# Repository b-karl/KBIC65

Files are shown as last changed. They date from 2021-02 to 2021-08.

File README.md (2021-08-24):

# KBIC65
A 65% [mechanical keyboard](https://keyboard.university/100-courses/intro-to-mechanical-keyboards) with a [ProMicro](https://deskthority.net/wiki/Arduino_Pro_Micro) controller footprint. Repository contains [KiCad](https://www.kicad.org/) PCB design files and 2D drawings in SVG of PCB, bottom plate, switch plate and acrylic window.

Bottom of keyboard has two alternatives. A design with glass rims inspired by my grandfather's glasses and a dithered image of the sun from the [NASA Solar Dynamics Observatory](https://svs.gsfc.nasa.gov/13641). Included below is also a [guide on creating dithered PCB art](#making-dithered-pcb-art-for-kicad).

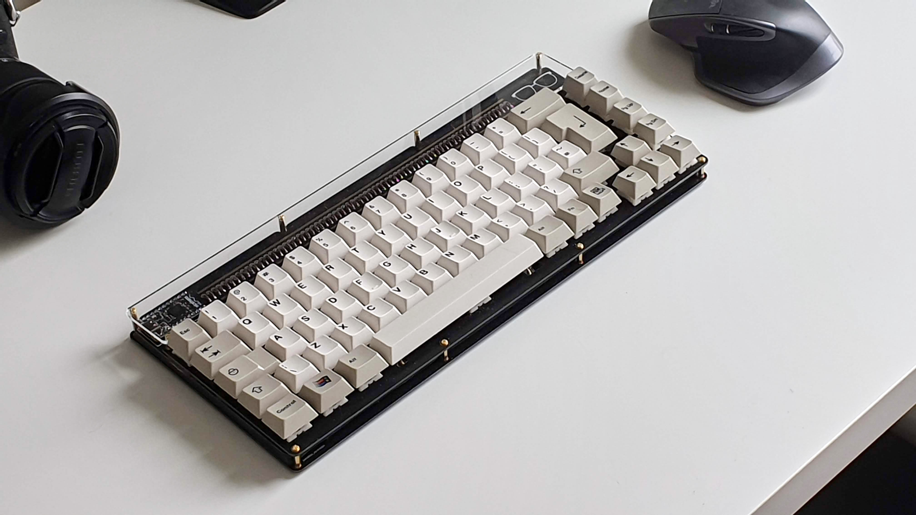
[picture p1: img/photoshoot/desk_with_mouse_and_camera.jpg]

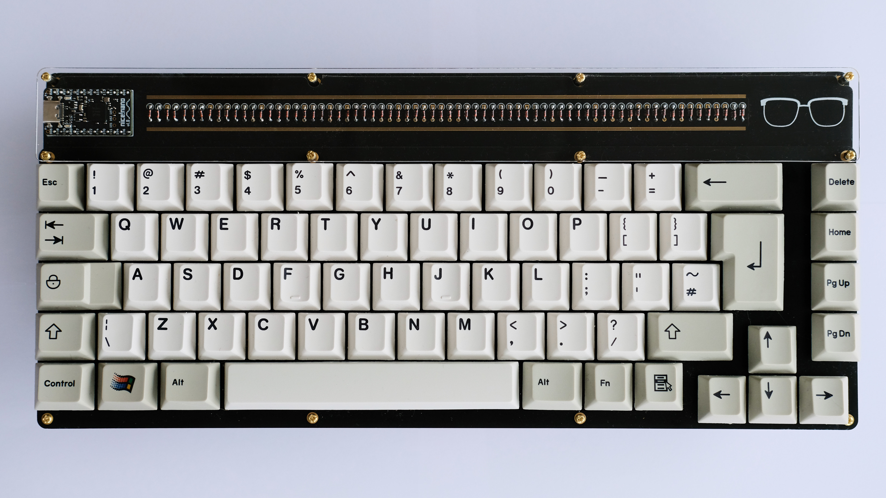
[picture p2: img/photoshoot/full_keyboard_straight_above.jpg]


[More photos](img/photoshoot/readme.md)

# Main features/focus
- Intended to be portable and wireless, but with a [through-hole technology (THT)](https://en.wikipedia.org/wiki/Through-hole_technology) style
- 65%/70 key layout with spaced arrow keys and right-side navigation row in the style of [Satistifaction75](https://cannonkeys.com/collections/group-buy/products/gb-satisfaction-75-keyboard-round-2) and many others
- ProMicro footprint to allow upgrade of the microcontroller, intended to be used with the [nice!nano](https://nicekeyboards.com/nice-nano/) and [ZMK](https://zmkfirmware.dev/) firmware for my personal build
- Designed to be mountable in both an open PCB stack or in a plate-mounted case (not yet designed)
- 8x9 wiring [duplex matrix](https://wiki.ai03.com/books/pcb-design/page/matrices-and-duplex-matrix) requiring only 17 pins on a ProMicro compatible controller

# Some design choices

- Reduced copper coverage on top of PCB and bottom plate, and no copper switch plate to improve Bluetooth signal
- Plate mounted with screws, the PCB contains drilled holes large enough to fit M2 spacers. I.e. the PCB is only connected to the plate via the switches.
- Tried to avoid vias, but have one (that I probably could have skipped)
- Since the bottom is symmetrical, there are two alternative design two choose from

# How to create your own
[See the v1.0 release](https://github.com/b-karl/KBIC65/releases/tag/v1.0.0) to find the files and list of parts to create your own. 
- Gerber zip-files are used to order the PCB, bottom plate and top plate from a PCB manufacturer, I used [JLCPCB](https://jlcpcb.com/). 
- The acrylic window can be ordered from any laser cutting firm working with acrylic, I live in Sweden and used [TechStation](https://techstation.se/en/). 
- For keycaps, switches and ProMicro-compatible controller (possibly also diodes) use a keyboard company in your region, I got my keycaps from [KBDfans](https://kbdfans.com/), diodes from a local electronics supplier and the rest from [Splitkb](https://splitkb.com/).
- Screws and stand-offs can be sourced from various places but are probably easiest to find on AliExpress.

I do not have dedicated assembly instructions, but if you are comfortable soldering you can probably make do using [my build log](build_log.md).
# Firmware
I decided to use [ZMK](https://zmkfirmware.dev/) for my build of this keyboard. Compared to the most common open source mechanical keyboard firmware [QMK](https://docs.qmk.fm/#/), ZMK is tailored for wireless keyboards. The two main reasons you should care to use ZMK instead of a bluetooth QMK fork are (1) much better power efficiency, i.e. longer battery life, and (2) the most commonly used Bluetooth chip uses drivers that are not compatible with the QMK copyleft license.

You can find my ZMK shield for the KBIC65 in [my ZMK config repository](https://github.com/b-karl/zmk-config).

If you want to use a non-wireless controller (like a ProMicro, Elite-C etc.), I have [created a QMK fork](https://github.com/b-karl/qmk_firmware/tree/add-kbic65-keyboard/keyboards/karlb/kbic65) that has been tested on the KBIC65 using an Elite-C rev 4.

# Layout options



# Components

## PCB Front

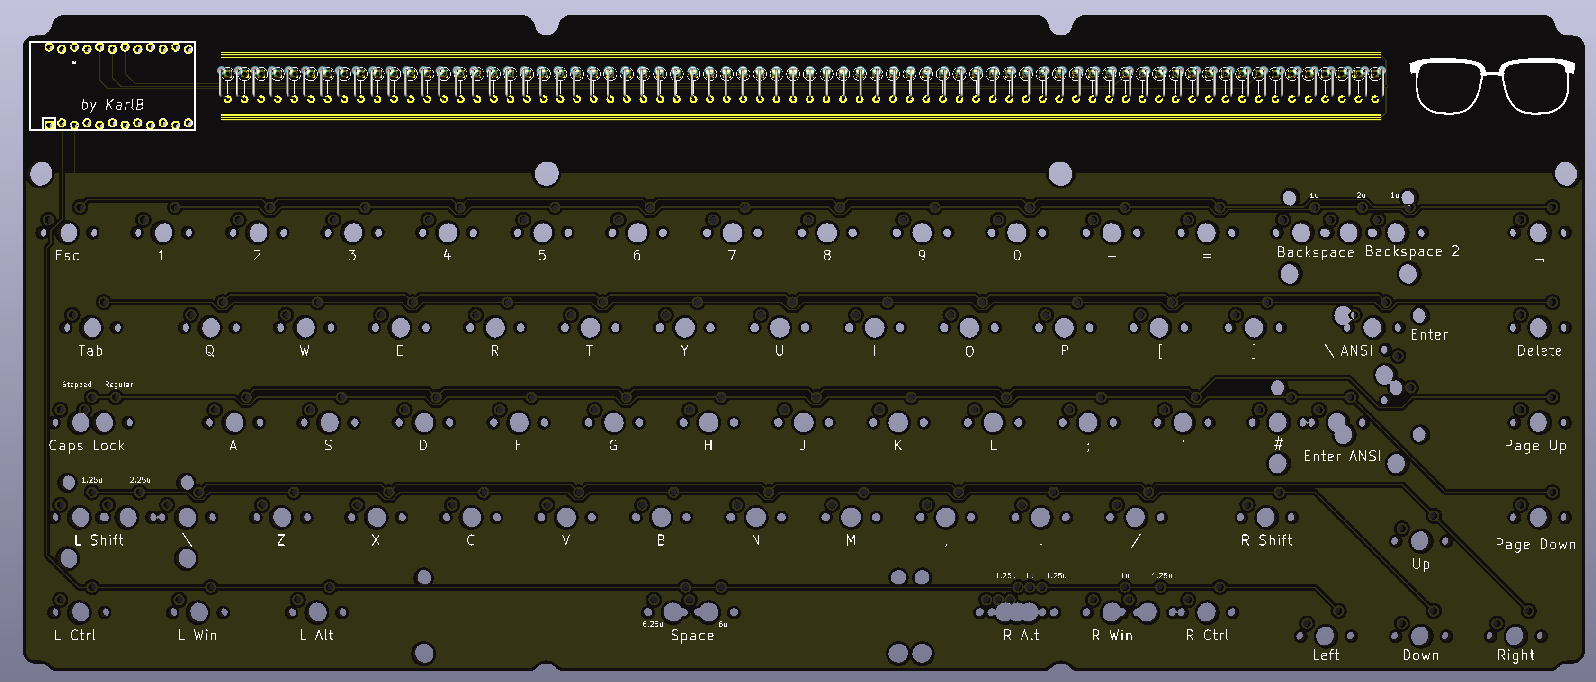
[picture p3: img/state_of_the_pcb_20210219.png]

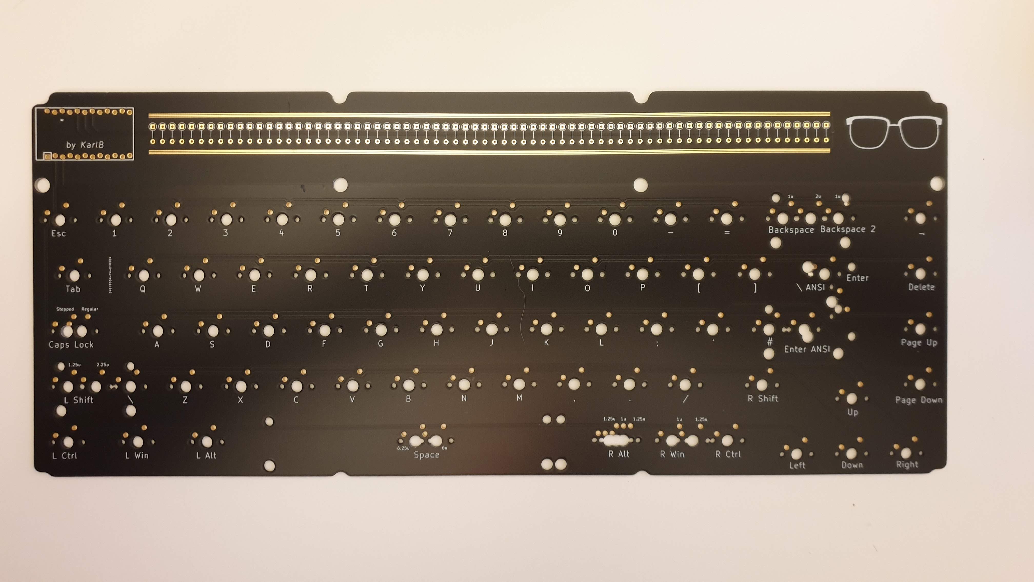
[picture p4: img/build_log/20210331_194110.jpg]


## Plate

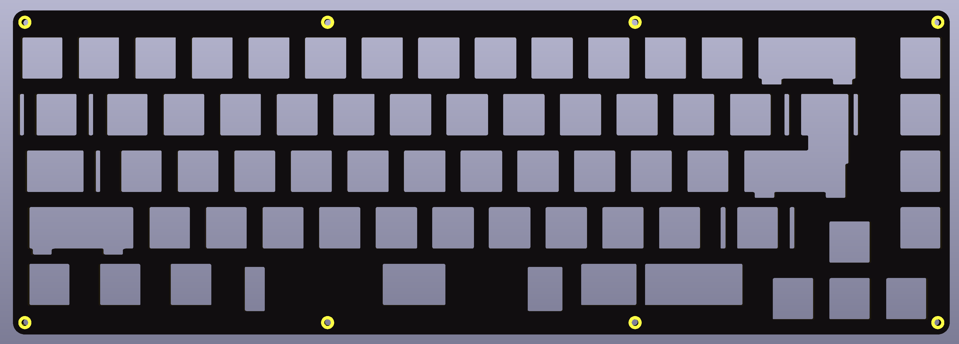
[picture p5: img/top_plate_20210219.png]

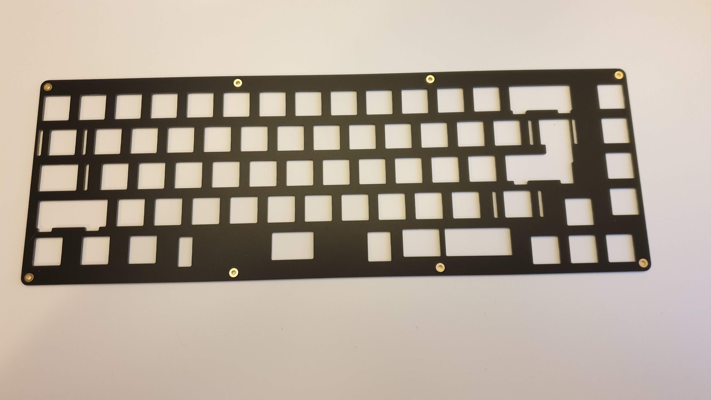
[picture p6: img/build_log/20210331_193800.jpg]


## Bottom Option 1 (PCB Front)

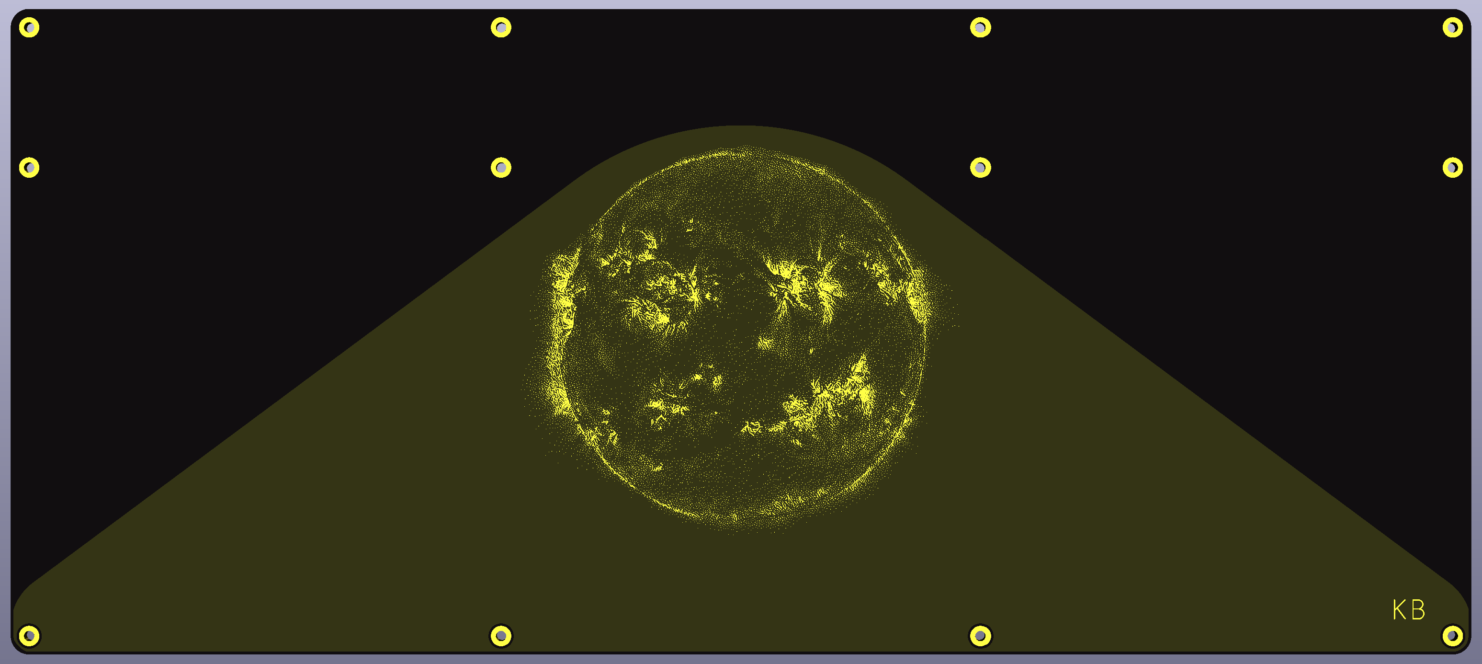
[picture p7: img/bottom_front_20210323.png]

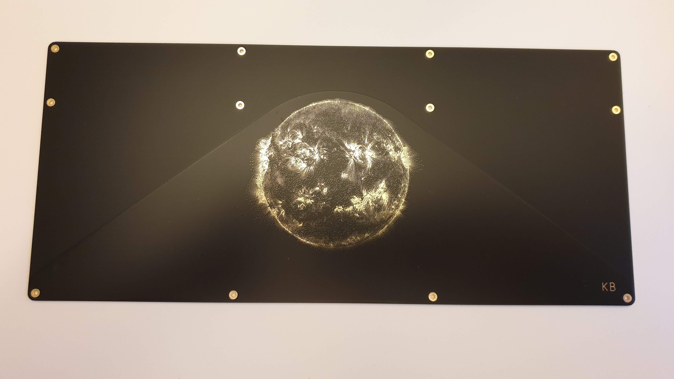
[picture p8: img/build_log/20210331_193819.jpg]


## Bottom Option 2 (PCB Back)

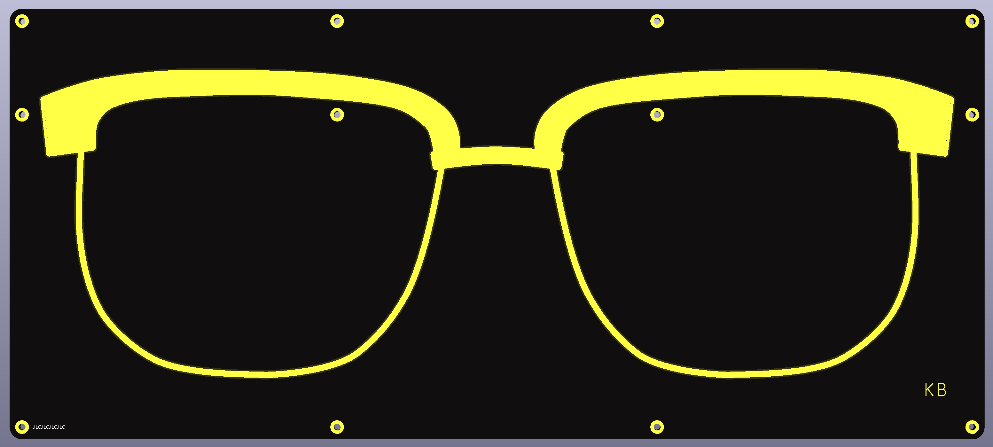
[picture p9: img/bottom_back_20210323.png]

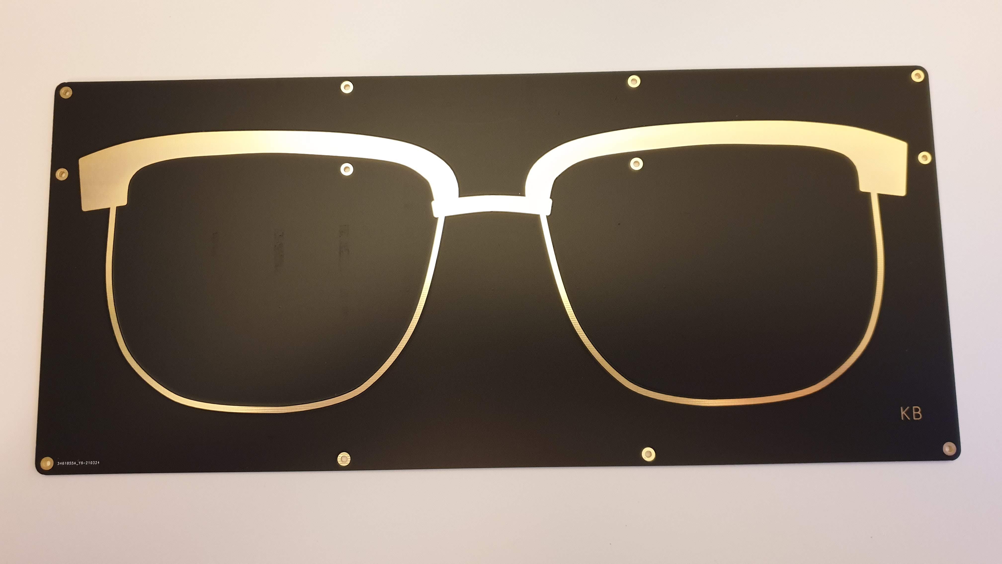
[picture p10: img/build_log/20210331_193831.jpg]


# Making dithered PCB art for KiCad
When I decided to make an alternative design for the bottom I eventually settled on trying my hand at a dithered image. This was a little trickier than I expected to get looking like I wanted (and still not sure how the end result will appear).

But generally here is the workflow I used in the end, and would recommend
- Settle on an image to use, crop it to only the part you want to place on the PCB. I settled on a NASA SDO image.


- JLCPCB and probably other PCB manufacturers can print at a resolution of about 0.15 mm which is equivalent to about 169 DPI. This means you should try to use 169 DPI or less, I used 169 DPI. Resize your image so that the resolution of the image at your selected DPI gives you the size you want on the board. I wanted my sun to be approximately 90 mm high so I resized to 600px high, which results in an image 90.2 mm high at 169 DPI. 
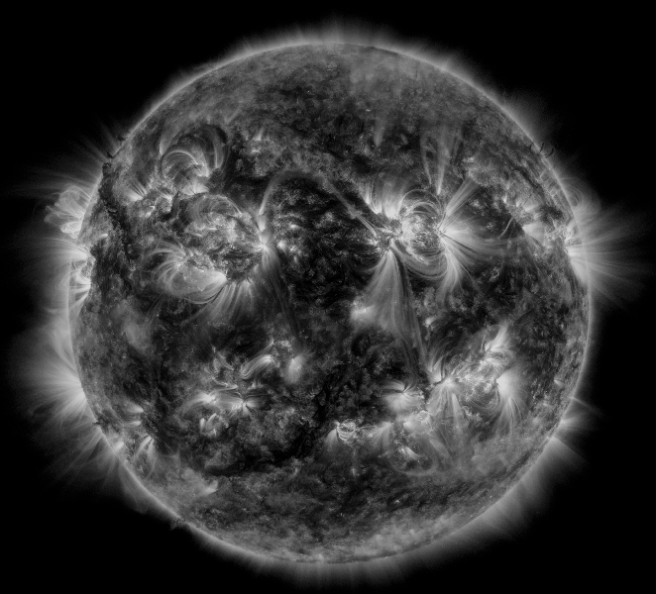
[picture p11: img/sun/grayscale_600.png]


- Use a dithering tool to dither your image and create a dithered copy. I strongly recommend [Ditherlicious](https://29a.ch/ditherlicious/) but you can look around for other tools you have handy.
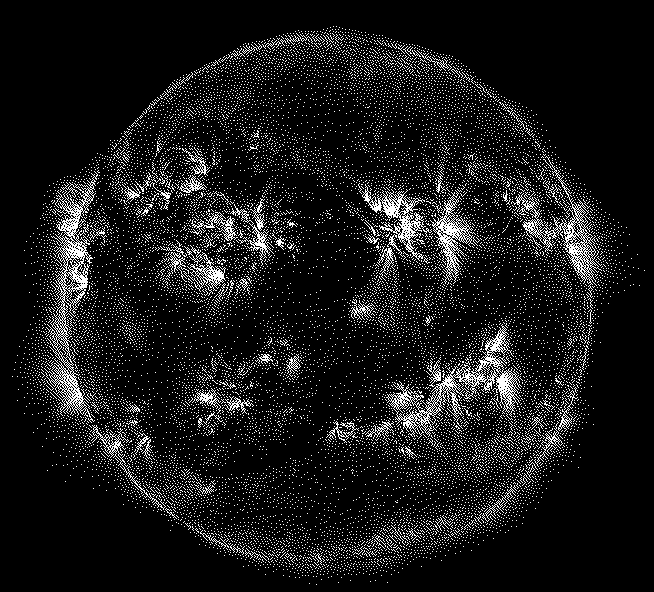
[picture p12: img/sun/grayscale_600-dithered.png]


- Open your KiCad project and then open Convert Image, a.k.a. the bitmap2component tool.
- Import your dithered image, select Negative if necessary, pick either Front Silk Screen or Front Solder Mask and enter your chosen DPI. Click export and put into a new folder that will become a new KiCad library for you.
- In Pcbnew or your KiCad project, open Preferences > Manage footprint libraries
- Add your new folder as a footprint library
- Import your new PCB art footprint onto your PCB
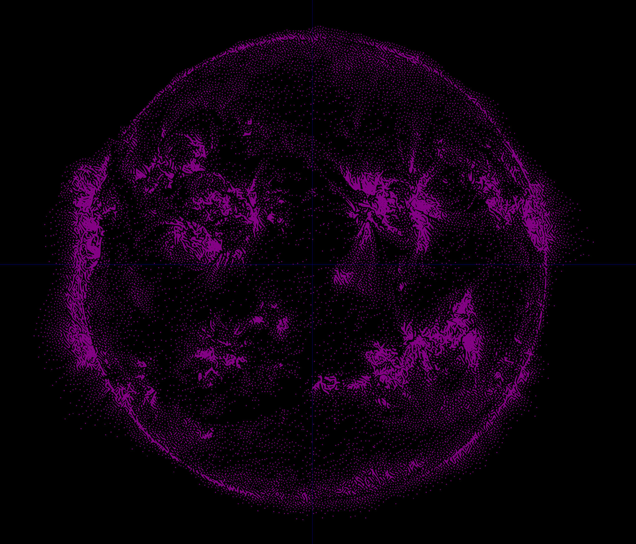
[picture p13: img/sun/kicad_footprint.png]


- Iterate, I played a lot with different dithering tools, changing the image histogram etc. The bitmap2component tool does not import dithered image exactly but blends pixels together, therefore I would recommend generating a few variants and comparing them in KiCad and possibly the 3D viewer. Please note that these images requires quite a bit of processing from KiCad. Updating the 3D view especially, which took about 1-2 min for me.

- Final result after ordering from JLCPCB with black solder mask and ENIG finish
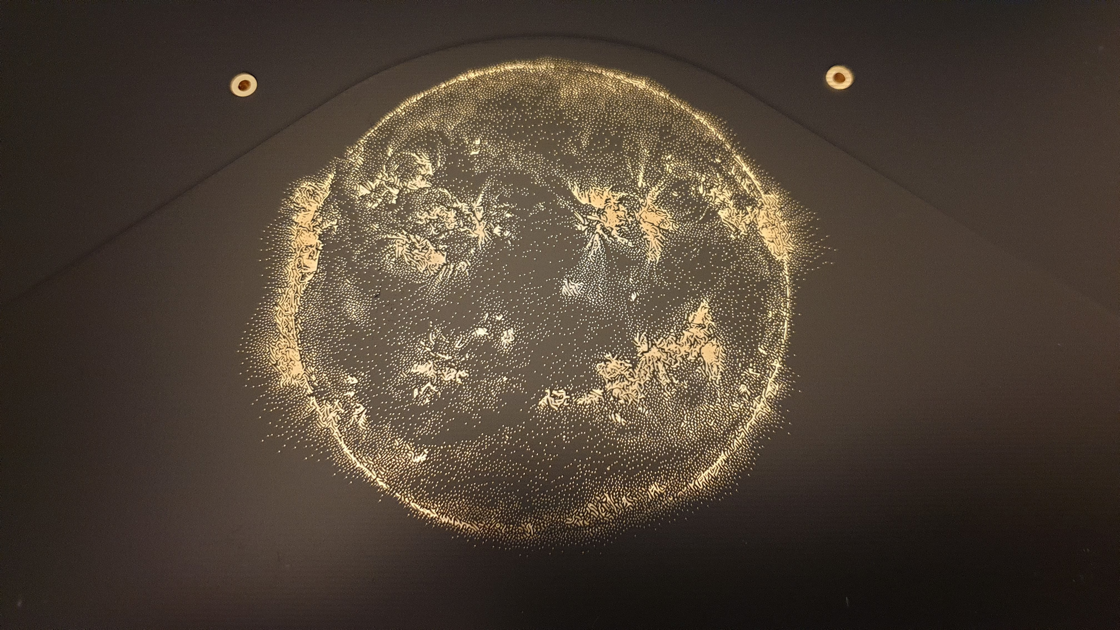
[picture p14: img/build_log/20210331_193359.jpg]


# Comparison to similar keyboards

## Discipline65
The [Discipline65](https://github.com/coseyfannitutti/discipline) is the original inspiration for this keyboard, along with the case making community that has been born around it. In the spirit of CFTKB the board design will also be open source.

Some of the main differences
- KBIC65 will use a dedicated ProMicro footprint instead of all the THT components in the Discipline65, a believe this makes the board more easy to upgrade at the cost of losing some of the THT aesthetic.
- The layers in the Discipline FR4 kit have the same outer dimension (excluding the top part of the plate), which is nice for a pure FR4-style keyboard but creates some limitations if one wants to create a case for it. The KBIC65 will have a minimal PCB given the layout (on the left, bottom and right sides) and a plate with overhang allowing for various types of plate-mounted case designs.
- The PCB will have holes large enough to fit M2 spacers between THT row and the layout. This allows the FR4 kit-style assembly to have the PCB completely free-floating and only the switch plate connecting directly to the bottom plate.

## Nibble65
The [Nibble65](https://nullbits.co/nibble/) is another board inspired by the Discipline65. It has an additional column of keys on the left, allowing also for rotary encoders and the top of this column houses a ProMicro footprint. 

Some differences
- The Nibble65 has similar limitations to the Discipline65 in terms of case design compatibility
- The Nibble65 uses multiplexers (I believe) to keep the PCB wiring simple and to add a bit to the THT aesthetic. The KBIC65 uses an efficient wiring matrix allowing for a full 65%/70 key layout without additional components.
- The Nibble65 has an extra column to the left, housing a ProMicro-footprint, some extra keys as well as a multi-purpose section for either rotary encodes, giant LED or an OLED screen.

# Possible future work
- Non-metal case
- Solar cell trickle charging panel instead of window
- Remove unintended silk screen from front PCB glasses
- Add holes for mounting a battery connector
- Move JLCPCB production number location (or get it removed in production)
- Change battery to something slightly thinner, sub-5 mm, but could be wider and longer than the current battery

# FAQ

### What does KBIC mean?
The original name KBIC65 is inspired by soldering and tinkering in my grandfather's workshop as a child and have named it with our combined initials KB and IC. But having spent quite a bit of time on making PCB art for the bottom of the keyboard based on an image from the [NASA Solar Dynamics Observatory](https://svs.gsfc.nasa.gov/13641) I am considering renaming it if I make anything more of it (or make a group buy at some point). I am open to name suggestions if you have one!

### Why don't you just buy keyboard X? It is cheaper and simpler than designing this.
I am doing this as a side project for fun, and the learning experience, and definitely not for profit.

If you want a 65% keyboard with the THT aesthetic get a [Discipline65](https://github.com/coseyfannitutti/discipline). If you want a 65% for your nice!nano, get the [Nibble65](https://nullbits.co/nibble/). If you just want something wireless but don't want to build it yourself, get a [Keychron](https://www.keychron.com/).

### I really want to make one myself, can you please fix the remaining issues?
Maybe, if you have some experience or willingness to learn, fork this repo and try to fix it yourself (and maybe do a PR on the end result). If you don't have the experience or know-how, send me a message so I know someone actually wants it and I will consider fixing it when I have time.

### This is just a rip-off of keyboard X. What gives?
I am trying to make my own thing but the design is of course heavily inspired by other keyboards, especially THT kits. Some honorable mentions

- [Nicell Dissatisfaction65](https://github.com/Nicell/Dissatisfaction-65)
A very similar keyboard to what I am designing, by the creator of the nice!nano. This uses a lot of the "early" techniques for what I feel a wireless open-source firmware was in 2019-beginning of 2020 such as Adafruit Feather BLE with QMK, something that is much better done today with the nice!nano (and similar controllers) and the ZMK firmware. Nicell is the creator of the nice!nano and also very active in the ZMK project.

- [CannonKeys Satisfaction75](https://ilumkb.com/blogs/news/satisfaction-75-r2)
My original inspiration for the layout

- [CFTKB Discipline65](https://github.com/coseyfannitutti/discipline)
Original inspiration for the THT design and the idea to make an FR4 kit first and a case after. The open-source Kicad files have also been a good sanity check, plus it has beautiful wiring!

- [Nullbits Nibble65](https://nullbits.co/nibble/)
A great take on the THT and would be my choice to buy if I didn't want to make something of my own but still make a nice!nano keyboard.

- [Lysol LCK75](https://p3dstore.com/products/lck75): No diode row but THT components otherwise and that arrow keys and navigation column stagger.

- [MujiManic Disarray65](https://sneakbox.com/products/disarray): Not exactly THT, but sooo much fun, beautiful wiring and one of the best case ideas ever. Case also comes in a version for the Discipline.

- [RMI-KB Herringbone75](https://rmi-kb.com/herringbone/): A fun variant on the Mysterium 75.

- [u/emdarcher Lattice 60%](https://keyhive.xyz/shop/lattice): Definitely contender for most innovative diode placement among THT keyboards

- [theksmith Discipline65](https://theksmith.com/hardware/designing-building-custom-mechanical-keyboard-2020/): Honorable mention on Discipline65 case design

- [4Bar60 by u/struct_Nodes](https://www.reddit.com/r/MechanicalKeyboards/comments/kyjpx3/my_girlfriend_surprised_me_with_a_breakup_before/)
I found this keyboard in the middle of my PCB design but it is very similar to my intended design, except being a 60% of course.

- [WorldspawnsKeebs Houndstooth](https://www.etsy.com/uk/listing/717316405/houndstooth-kit-does-not-include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)
A split ortholinear 4x6 with a nice take on a clear case

- [Seoulcialite Argyle60](https://geekhack.org/index.php?topic=106255.0)
Great case for a THT kit and very interesting with side windows instead of placed above the key layout. Inspiration for moving the ProMicro footprint and diode row up 1/4 units to allow top case to have a divider between main layout and THT window.

- [EBastler Isometria75](https://github.com/ebastler/isometria-75)
Makes me want to try to change the key spacing on my keyboard, but I am unfortunately not brave enough.

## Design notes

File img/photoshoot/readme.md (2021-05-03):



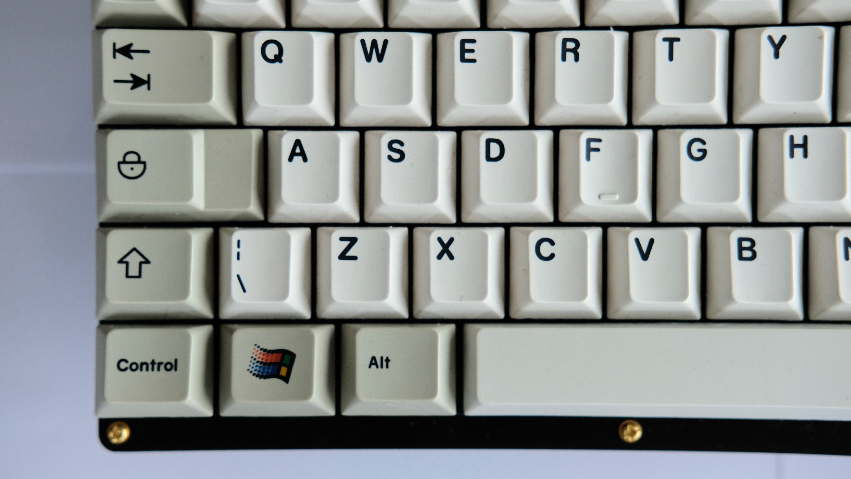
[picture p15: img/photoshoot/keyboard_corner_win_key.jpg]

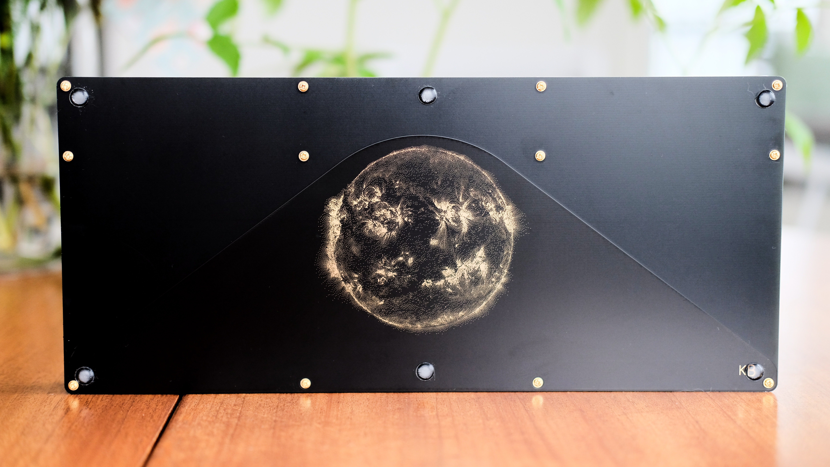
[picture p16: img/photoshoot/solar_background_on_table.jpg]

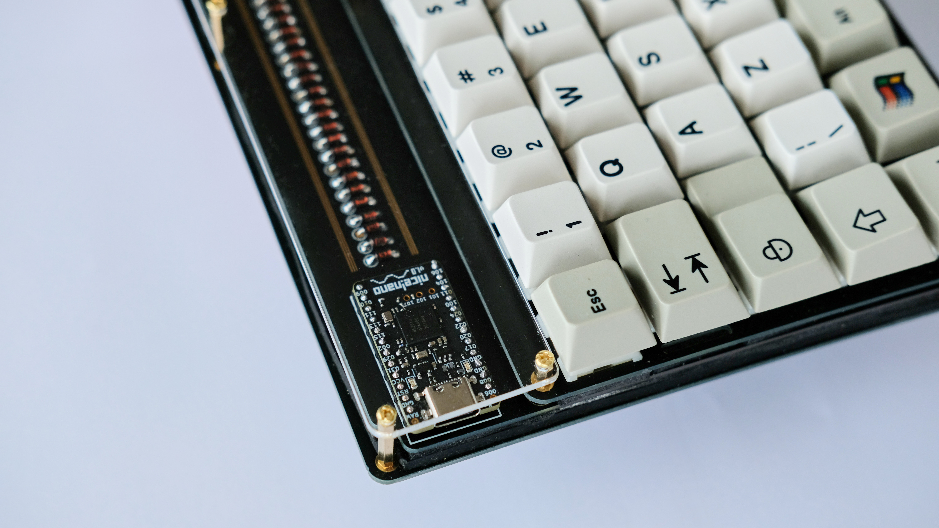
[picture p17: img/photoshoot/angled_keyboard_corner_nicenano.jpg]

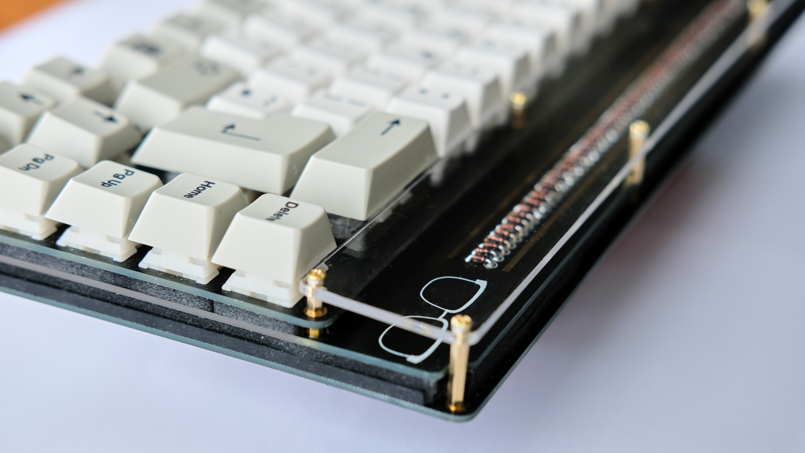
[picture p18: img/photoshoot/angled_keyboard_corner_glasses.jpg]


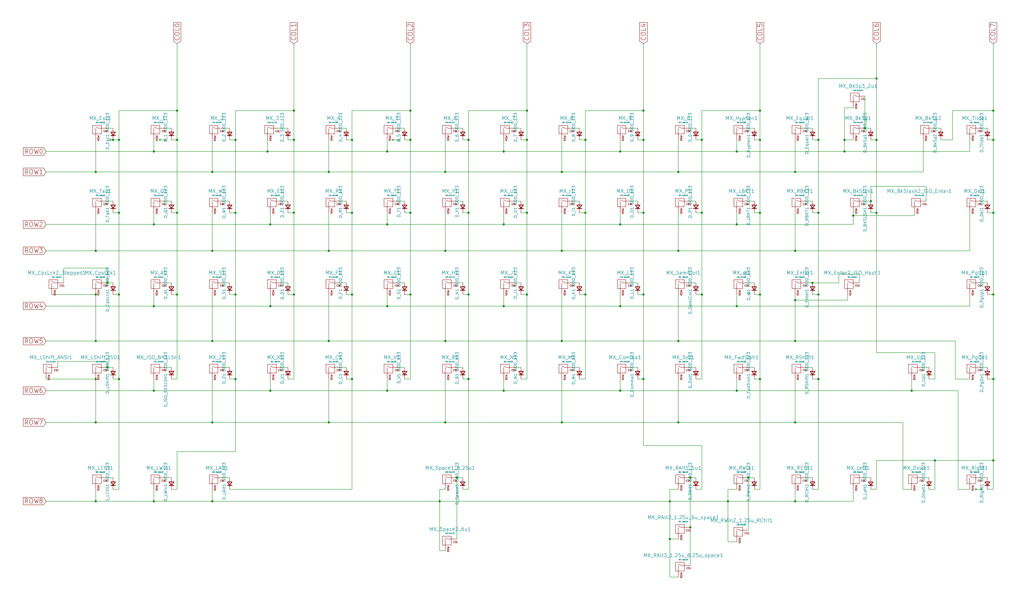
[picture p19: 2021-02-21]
img/matrix_schematic.png

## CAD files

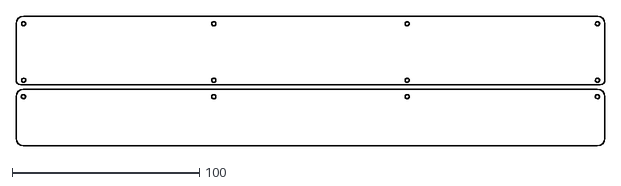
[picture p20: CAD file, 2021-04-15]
drawings/Window_Combined.dxf
314.4 x 69.1

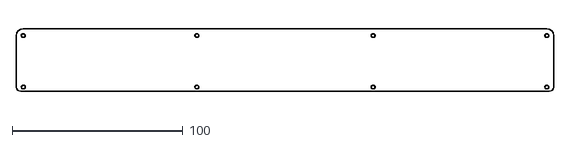
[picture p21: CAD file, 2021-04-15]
drawings/Window_Large.dxf
314.3 x 36.5

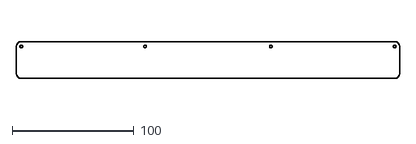
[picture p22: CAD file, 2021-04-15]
drawings/Window_Small.dxf
314.3 x 30.2

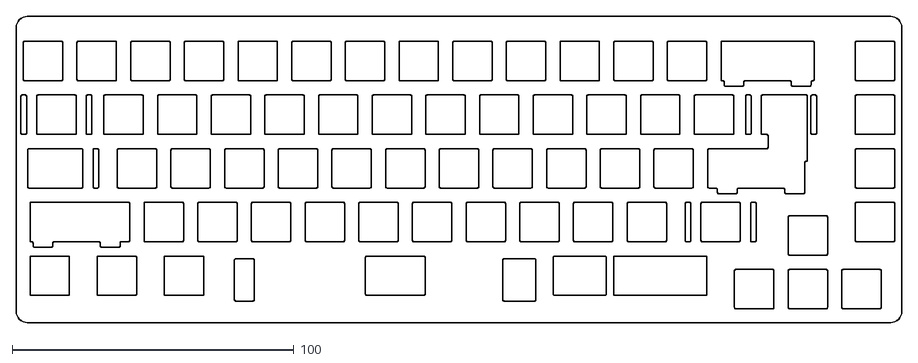
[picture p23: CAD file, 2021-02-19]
drawings/Plate_Outline.dxf
314.3 x 108.7

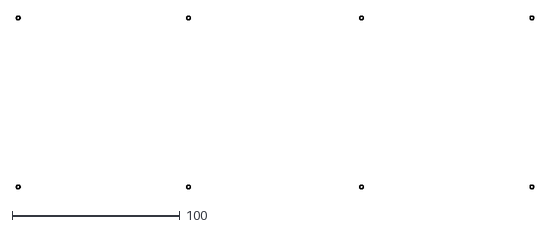
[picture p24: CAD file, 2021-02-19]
drawings/Plate_Holes.dxf
308.7 x 103.1

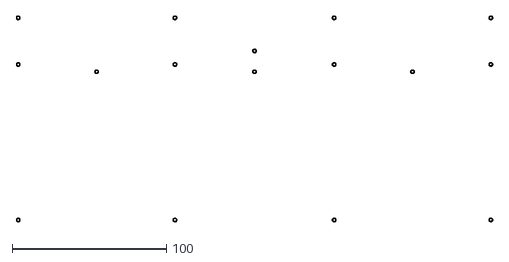
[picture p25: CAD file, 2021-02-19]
drawings/Bottom_Holes.dxf
308.7 x 133.3

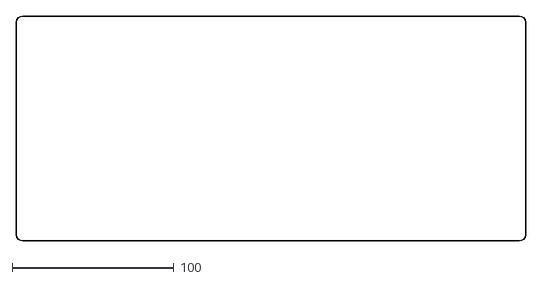
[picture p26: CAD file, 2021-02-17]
drawings/Bottom_Outline.dxf
314.3 x 138.9

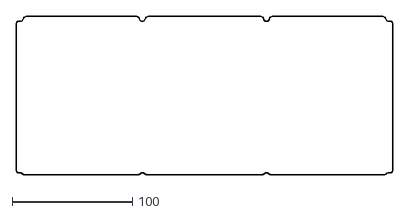
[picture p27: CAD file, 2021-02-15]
drawings/PCB_Outline.dxf
313.3 x 131.6

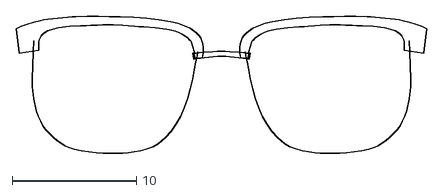
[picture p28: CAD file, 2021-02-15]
drawings/PCB_Silkscreen.dxf
33.0 x 11.1

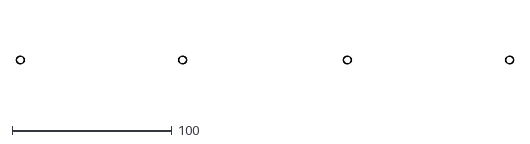
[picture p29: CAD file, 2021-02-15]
drawings/PCB_Holes.dxf
311.4 x 5.22

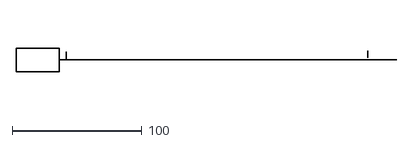
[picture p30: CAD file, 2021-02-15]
drawings/PCB_TopReference.dxf
293.4 x 17.8

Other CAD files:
drawings/Bottom_Silkscreen.dxf

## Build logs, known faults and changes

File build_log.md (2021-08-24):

# KBIC65 Build Log
Overview of build steps
- Prepare nice!nano
    - Set up ZMK and generate uf2 file
    - Load firmware with keymap
- Prepare foam/rubber layers (optional)
    - Attach plate foam
    - Cut out neoprene sheet
- Prepare bottom plate
    - Attach rubber feet
    - Attach spacers to align components
- Prepare PCB
    - Solder on diodes
    - Socket nice!nano
    - Test PCB
- Prepare and attach stabilizers
    - Stabilizer foam / band-aid mod
    - Clipping (not necessary)
    - shrink tube mod (reverted after testing)
    - Lube
    - Attach stabilizers
- Assemble plate-PCB package
    - Attach and solder on switches
    - Test assembled module
- Assemble keyboard without battery
- Test keyboard
- Add battery
- Test again (now with Bluetooth!)
- Put on keycaps
- Enjoy!
- Remember you were supposed to put on am acrylic window, order it and wait

# Recommended components
- 1 KBIC65 PCB
- 1 KBIC65 bottom plate
- 1 KBIC65 switch plate
- 1 KBIC65 2 mm acrylic window
- 1 [nice!nano](https://nicekeyboards.com/nice-nano/)
- 70 [1N4148 diodes](https://en.wikipedia.org/wiki/1N4148_signal_diode)
- 6 domed rubber feet
- 24 M2 x 4 mm brass bolts
- 8 M2 x 10 mm female-female brass standoffs
- 4 M2 x 15 mm female-female brass standoffs
- 4 M2 x 3 mm male-female brass standoffs
- 70 MX-style switches

Bolts and standoffs are most easily acquired via AliExpress, at least in Sweden where I am.

And if you want to put in foam
- 3-5 mm bottom-PCB foam or rubber (there is 3 mm clearance, 5 mm requires cutting out holes around pins sticking down). I used [3 mm neoprene](https://www.swedol.se/neoprengummipg-1001022.html) plus some leftover plate foam on the sides to seal it.
- [Plate-PCB foam](https://kbdfans.com/collections/keyboard-foam/products/kbdfans-module-foam)

# Prepare nice!nano
I had been looking at how to create a custom wireless keyboard for a while. My initial research suggested using an Adafruit Feather BLE with QMK, such as the [Dissatisfaction65 by Nicell](https://github.com/Nicell/Dissatisfaction-65), but luckily just a few months earlier Nicell himself had created the nice!nano controller, which is a ProMicro footprint Arduino close with Bluetooth. Even better, I found there was a relatively new keyboard firmware project called [ZMK](https://zmkfirmware.dev/), that addressed a bunch of the issues that QMK has with wireless. The two primary issues resolved by ZMK is (1) more battery-efficient scanning algorithms to improve battery life and (2) a license that is compatible with the Bluetooth libraries since QMK is not legally compatible with the libraries required to run Bluetooth chips.

In addition, however, ZMK has learned a lot from how QMK is used and also improved other aspects of the project, such as minimal user repositories that hosts your personal keymap and keyboard configurations and that then builds the ZMK firmware using GitHub Actions. A really neat setup in my opinion. Of course, they still don't have VIA or something like the QMK web tool, but in my case I was building my own PCB and matrix and therefore would need to dig into some code either way.

ZMK has pretty good documentation, but it also helped looking at other ZMK user repositories. My recommended reading guide order someone new to ZMK and that would like to replicate my work would be
1. [Read the introduction](https://zmkfirmware.dev/docs/)
2. [Read the FAQ and understand the difference between board and shield](https://zmkfirmware.dev/docs/faq)
3. [Set up a ZMK user repo](https://zmkfirmware.dev/docs/user-setup)
4. [Create a new shield](https://zmkfirmware.dev/docs/development/new-shield/)

I then used the [Nibble ZMK shield](https://github.com/zmkfirmware/zmk/tree/main/app/boards/shields/nibble) as a reference, there are probably better options though since the Nibble has an extra column to the left, a multiplexer for the matrix and support for rotary encoders, all of which I didn't need for my build.

I then created a first keymap, pushed to my [personal config repo](https://github.com/b-karl/zmk-config) and with some [ZMK GitHub Actions magic](https://github.com/b-karl/zmk-config/actions) I could download a uf2 file to flash my nice!nano with.

The nice!nano was super-easy to flash with a new firmware since it uses a bootloader that makes it show up as a mass-storage device. Then it is simple copy-paste or drag-and-drop of the new .uf2 file to the device and once the transfer is complete it automatically flashes itself and voilà, a new keyboard is detected.

# Prepare foam and rubber
## Plate foam
This is my second keyboard build, my first was a KBD75v2 kit from KBDfans. For that build I got [plate foam](https://kbdfans.com/collections/keyboard-foam/products/kbdfans-module-foam) and I had enough leftover to also cover this build. The modular plate foam is most easily placed using a tweezer to avoid deforming the pieces to much before the glue touches the plate. I also tried to keep the surrounding edges clean since they will be visible from the sides. 

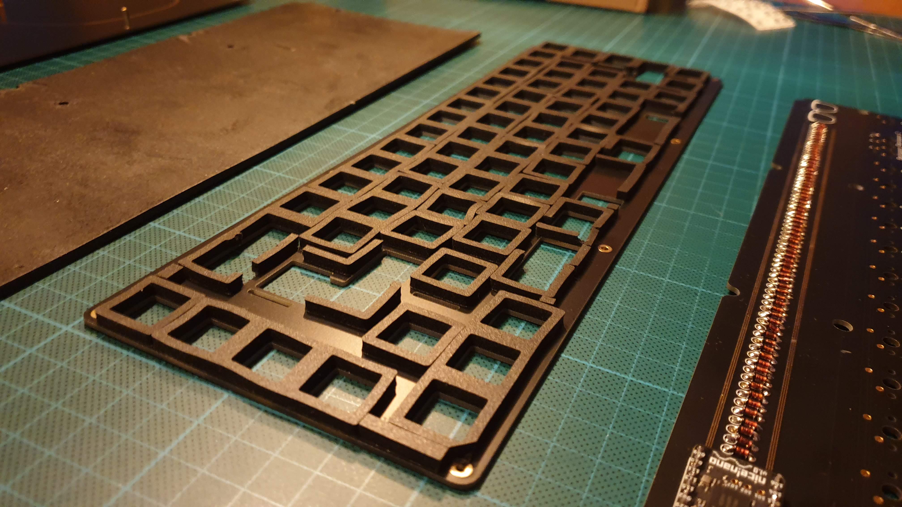
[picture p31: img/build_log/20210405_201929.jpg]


Unfortunately, I was a little too eager with covering everything. It turned out when I was assembling the plate and PCB  that some of the foam I had put in around the stabilizers was pressing on them, so I had to disassemble my work so far and clean up all the foam above and below the stabilizer mounts and along the stabilizer wire.

## Case foam/rubber
To add some weight and sound dampening without impeding the wireless signal too much, I decided to add a [3 mm thick neoprene rubber](https://www.swedol.se/neoprengummipg-1001022.html) cutout between the PCB and the bottom plate. I took one of my spare PCBs and used it to draw the outline on my neoprene sheet and then I used a carpet knife and a hole puncher to create the shape.

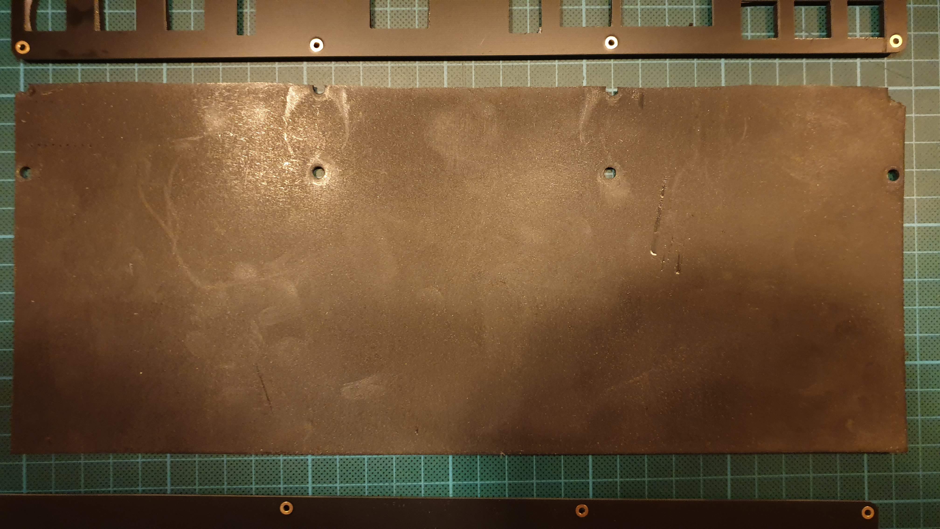
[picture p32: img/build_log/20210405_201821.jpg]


### Some notes on silencing a mechanical keyboard (or controlling sound profile)

Doing some research on how to dampen the sound of the keyboard (since I want to use it at my office in the future without pissing off my colleagues) the factors that I have understood to be most important, and think makes sense from my limited experience with two keyboards are the following

- Use a silent linear, silent tactile, linear or tactile switch (on order of most to least silent), a clicky switch is by definition not silent.
- Weight is one of the most important factors, the heavier the better so metal cases are better than plastic ones. This goes in conflict with a wireless build so I opted to aim to make the keyboard as heavy as possible without using metals that might shield the Bluetooth signal.
- Put the keyboard on a soft desk mat.
- Fill up hollow spaces in the keyboard with foam, rubber or some other material. Foam makes most sense usually since it probably has the least impact on the flexibility and motion of the plate and thus the give with each keystroke.
- Use a softer plate material, aluminum is usually considered OK among metal but brass and steel might cause ping sounds.
- Band-aid mod stabilizers and possibly shrink tube mod them.
- Lube stabilizers
- Lube switches

If you have done all of the above and want to try something else, you can try - Putting O-rings on the key cap stems. The idea with this is that it will dampen the sound when bottoming out, but it might also make the keys feel more mushy and reduces key travel somewhat. If and how well it works also depends on your key cap profile and materials. This mod is a very loaded subject on r/mk and I think it has very little impact compared to the points above.
- Fill larger keycaps, or if you're extreme all keycaps, with foam to remove and reverb inside the keycap. This mod is most commonly done for the space bar.

### Choice of case foam
Since I wanted my case foam to both be a good sound absorber and provide as much weight as possible the options I found most suitable were:
- Sorbothane: Expensive and hard to get in a good size if you have an open case design as my first iteration will be
- Butyl rubber or similar: Used for sound deadening in cars and the best alternative I found was something like [Dynamat Dynaliner](https://www.amazon.com/Dynamat-11101-Dynaliner-Self-Adhesive-Deadener/dp/B001KM9C4C). Issues with this was once again price but I also read that it can smell quite a bit and it takes a while before the smell goes away, which again is maybe not the best choice with an open case design. The benefit would, however, be that it is probably the heaviest of the options around.
- High-density EVA foam: Relatively cheap but dense foam commonly used for cosplay and role playing.
- Neoprene rubber: Also relatively cheap and available.

Comparing these I ruled out sorbothane and butyl rubber, leaving HD-EVA and neoprene. Out of these I then looked up the common densities of these materials and neoprene won by a small margin so I settled on neoprene.

# Prepare bottom plate
As they always say in keyboard build videos, start with putting rubber feet on your case to protect it from scratches. In addition, it will also be nice to occasionally use the bottom and neoprene sheet as a base when working with the PCB and plate.

For screws and spacers I wanted them to be in brass, or look like golden brass at least. This was a bit tricky to find in Sweden, but I eventually learned that Amazon is a pretty good source for random screws and I picked up [this kit](https://www.amazon.se/gp/product/B087N3Z4RY/ref=ppx_od_dt_b_asin_title_s00?ie=UTF8&psc=1), giving me some flexibility if I want to play with the mounting. I attached 10 mm spacers to the bottom and then put the neoprene on for the moment. The neoprene feels like a good soft surface to rest the PCB once diodes, controller and switches are soldered in.

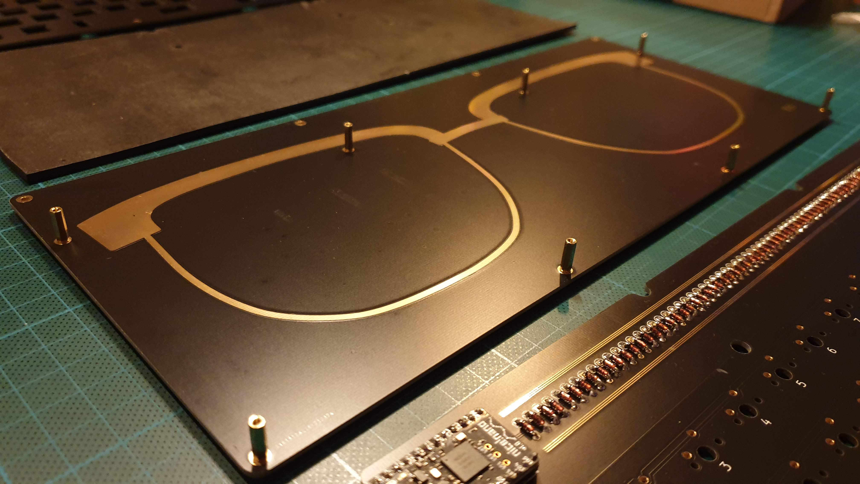
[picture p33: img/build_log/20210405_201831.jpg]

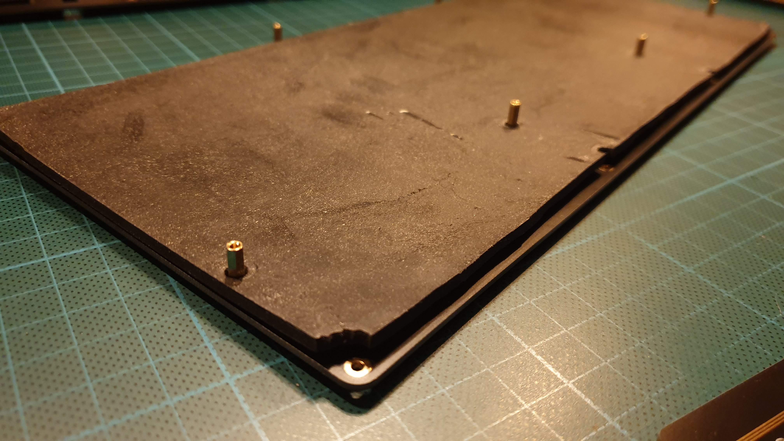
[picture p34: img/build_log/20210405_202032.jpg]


# Prepare PCB
There is no real test like getting something to run in real life. I ran checks in KiCad when developing my PCB and in addition, JLCPCB do probe testing to check the PCB. I could, of course, have messed up something more fundamental in my design that wouldn't be caught in any of these checks.

To get the PCB up and running required two general steps
- Attach the nice!nano (which I did by socketing it so I can remove it easily if I want).
- Solder in diodes for all switches.

This is essentially just a bunch of soldering and ended up like this for me:
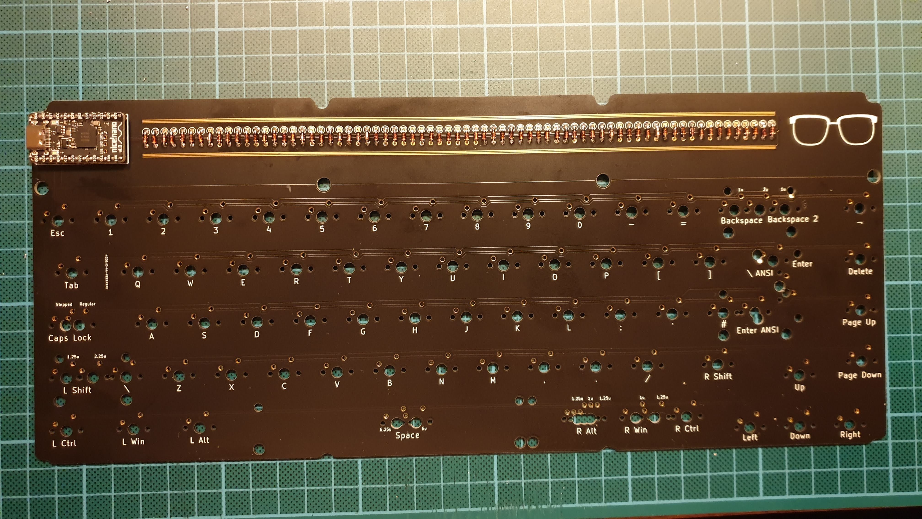
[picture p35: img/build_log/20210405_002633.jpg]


The tricky part, compared to soldering switches is that these joints are very visible and since the are on one long line, any inconsistencies show easily. I initially tried bending multiple diodes together when they where still in their package tape but I don't think it really worked better than just bending them one by one with my hands. This was also partially due to the footprint I selected for the diode essentially requiring the diode legs to be bent as close to the diode as possible.

One thing I would be more careful about if I did it again would be to try to be consistent with the amount of solder I used and the amount of time I spent heating up the solder and components. One of the aesthetic issues with the final result is that the solder came through from the back of the board and filled part of the front for several diodes, but not all, and this is probably the inconsistency that bothers me the most.

# Prepare and attach stabilizers

For stabilizers I got [Durock screw-in stabilizers v2](https://keygem.store/products/durock-screw-in-stablizer-v2-set?_pos=4&_sid=b89e1c812&_ss=r) with transparent plastic and brass/golden metal details. It was the stabs I could find that I think would go best with the rest of my build (black, white and gold).

## 6u stabilizer
For my first build with this PCB I wanted to use a 6u space bar to allow for a 1.25u Right Alt, which is heavily used when typing with a Swedish (or any ISO) layout. I knew they aren't that common, but luckily the ePBT 9009 kit I got for this keyboard has multiple 6u space bars to choose from. However, later when buying stabilizers I found out that 6u stabilizers are probably even more rare, especially if you want them looking a certain way. Doing a bit of research, the best course of action seemed to bend another stabilizer wire (or some other metal wire) to the correct length. Luckily, my Durock stabilizer set came with a 7u stabilizer wire that I have no plan on using so I took some pliers and a small vice and bent it to the correct size. I had to iterate once, my first bend made the wire slightly too long and it put some unwanted pressure when in stabilizer mount but lucky enough I was able to re-bend it to a good size. 

## Clipping
The Durock stabilizers are designed to not require clipping so did not have to do this step.

## Stabilizer foam/ band-aid mod
Instead of doing the actual band-aid mod I was lazy and picked up some [KBDfans stabilizer foam stickers](https://kbdfans.com/products/kbdfans-stabilizers-foam-sticker=) when ordering some other stuff.

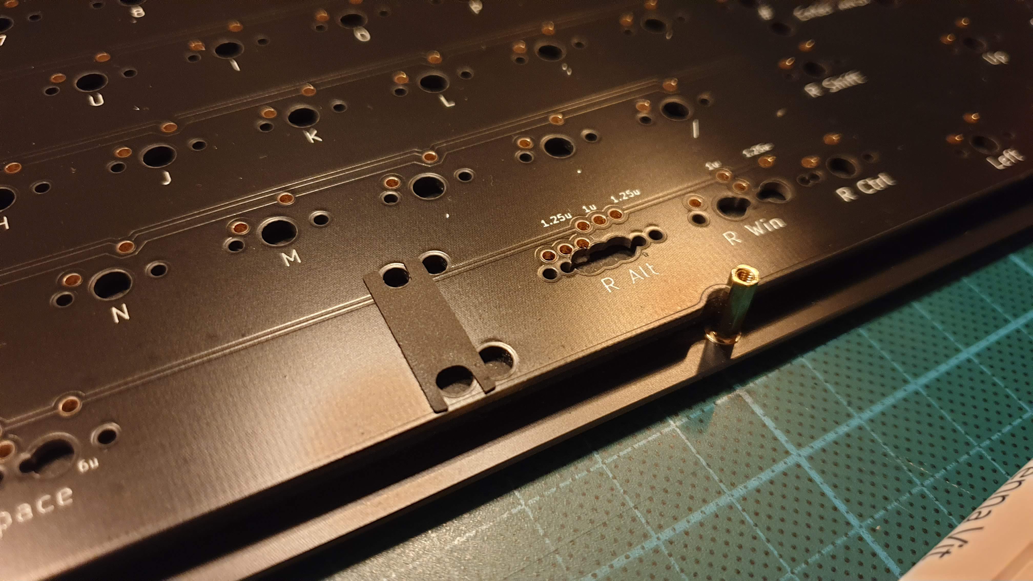
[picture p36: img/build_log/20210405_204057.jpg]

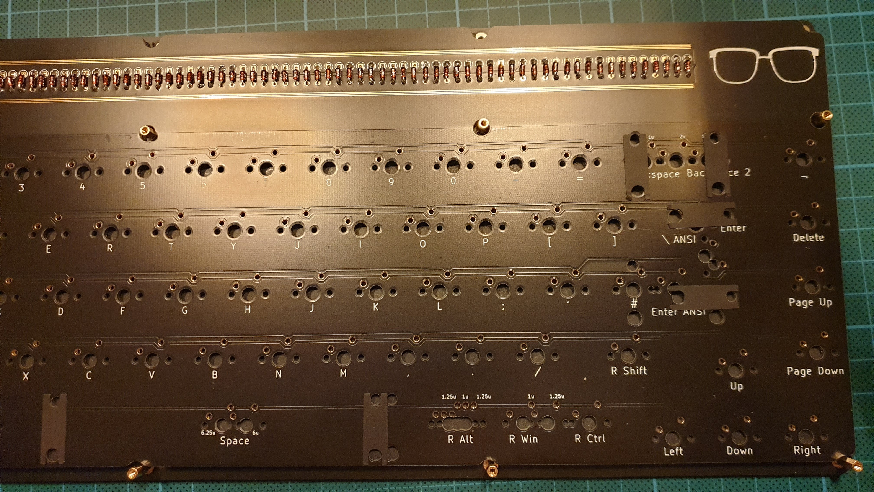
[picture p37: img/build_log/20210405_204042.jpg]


## Shrink tube mod (failed/removed)
I had some shrink tube laying around that I thought I could try doing the [shrink tube mod](https://rama.works/guides#/silencing-stabilisers/) with. However, I think the shrink tube might have been too big or maybe it doesn't work as well with the Durock v2 stabilizers, but the stabilizers ended up sticking and being sluggish so I decided to remove them instead.

## Lube
Used Krytox 205g0 to lube the switches since it was the best thing I had available at home.

## Attaching
After adding the stabilizers and beginning to solder in the first switches I discovered that some of the plate foam I had put it was pressing on the stabilizers, both on the screws (making )

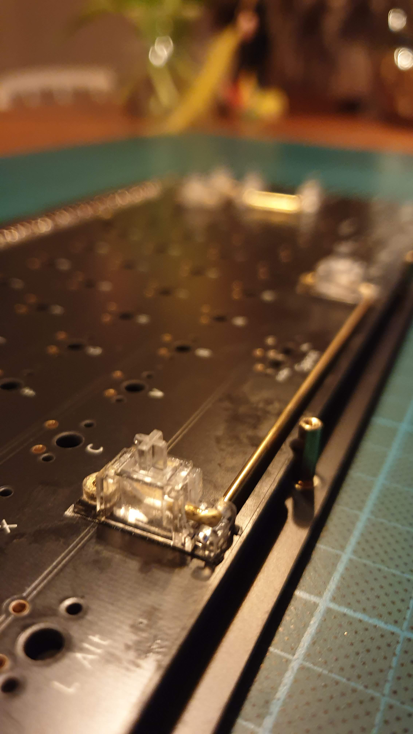
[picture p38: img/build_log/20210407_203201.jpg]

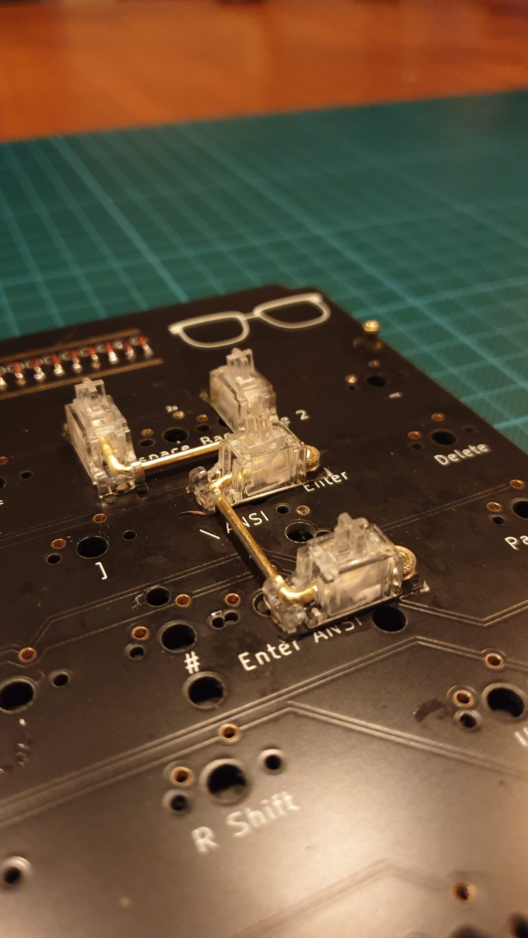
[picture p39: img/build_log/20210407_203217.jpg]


# Assemble plate-PCB package
The next step was to put together the plate, prepared PCB and all the switches. My choice of switch for this build was the [Gazzew Boba U4](https://splitkb.com/products/gazzew-boba-u4-silent-tactile-switch), a silent and very tactile switch, which I am very satisfied with (since I am using them to type out this build log).

This is pretty well covered in any build log or video, but a good trick is to start with attaching the corner switches. I then also soldered in the switches for keys with stabilizers since I wanted to make sure those keys felt okay before I continued (in case I had to remove all switches and modify the stabilizers, which I did do once).

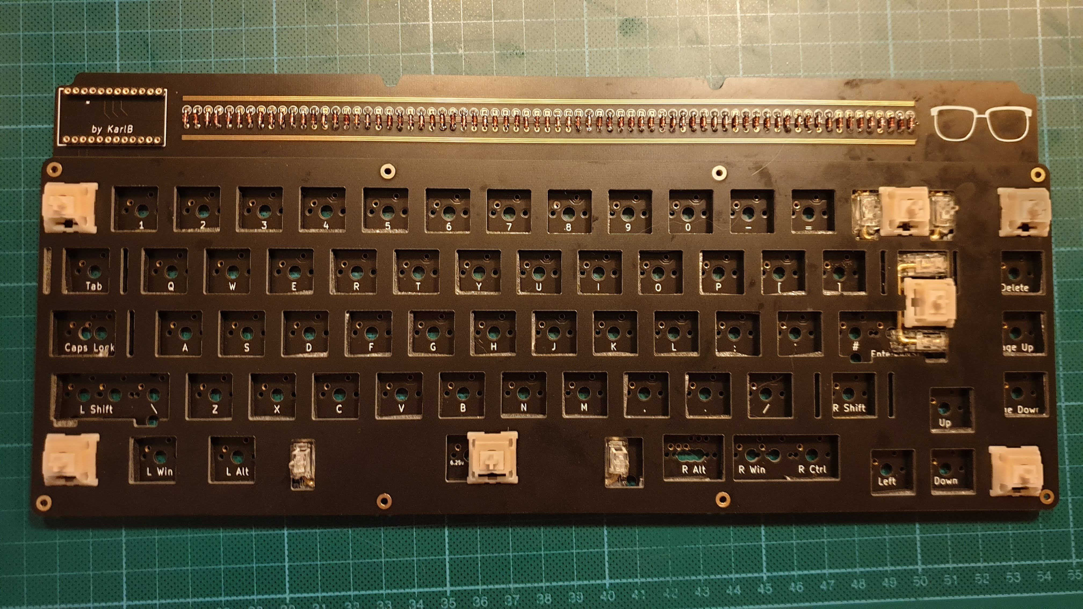
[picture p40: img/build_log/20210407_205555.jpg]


Once you have the corners in place, it is fairly easy to attach and solder multiple switches at ones, I did them row by row, and you end up with a plate-PCB package with switches. Almost a full keyboard now!

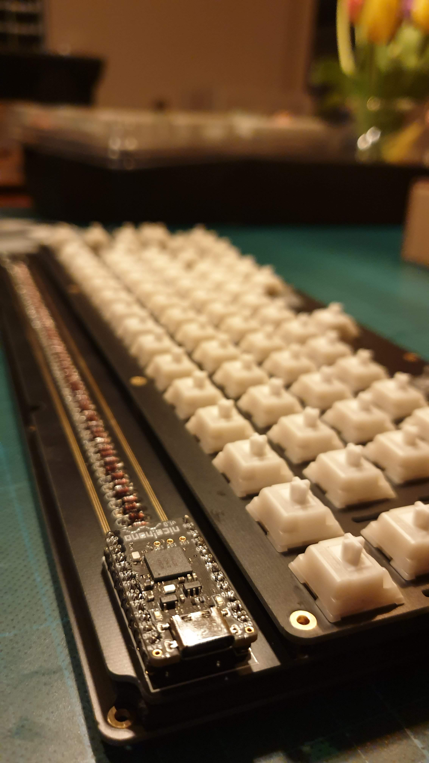
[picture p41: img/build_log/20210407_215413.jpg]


# Test without battery
Just to make sure I didn't fuck anything up I went back to the computer and made sure the assembled package worked before moving on to attaching the battery.

# Attaching the battery
This was the part of the build I was the least sure of how I was going to do. I had bought a [130 mAh LiPo battery](https://www.electrokit.com/produkt/batteri-lipo-3-7v-130mah/), since I had trouble finding the slightly smaller 301230 110 mAh battery in Sweden that is [recommended when mounting it under a socketed nice!nano](https://nicekeyboards.com/docs/nice-nano/). I was, however, able to find a pretty good solution (in my opinion) since the space between the bottom and PCB ended up being 5 mm with my chosen spacers.

I soldered on a connector with wires to the ground and VCC pins on the back of the PCB and routed so that I could place the battery in the areas with no soldered components with legs sticking down.

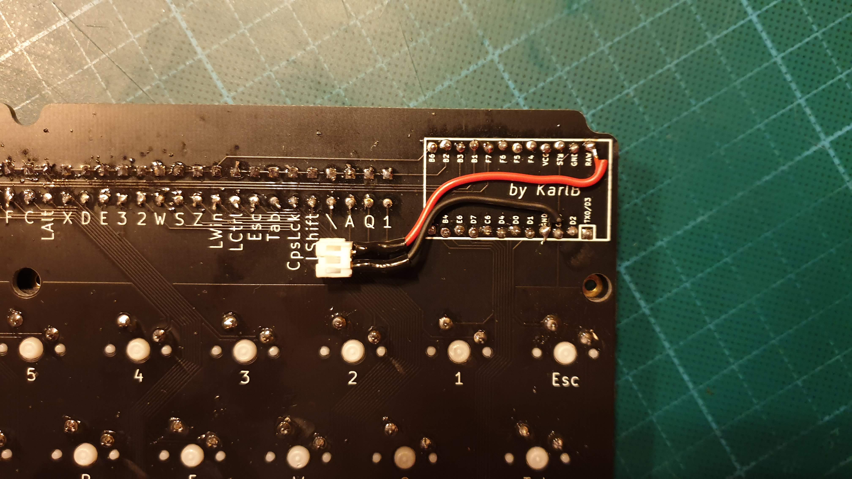
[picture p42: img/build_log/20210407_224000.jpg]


I then made a cut out in the neoprene to house the battery.

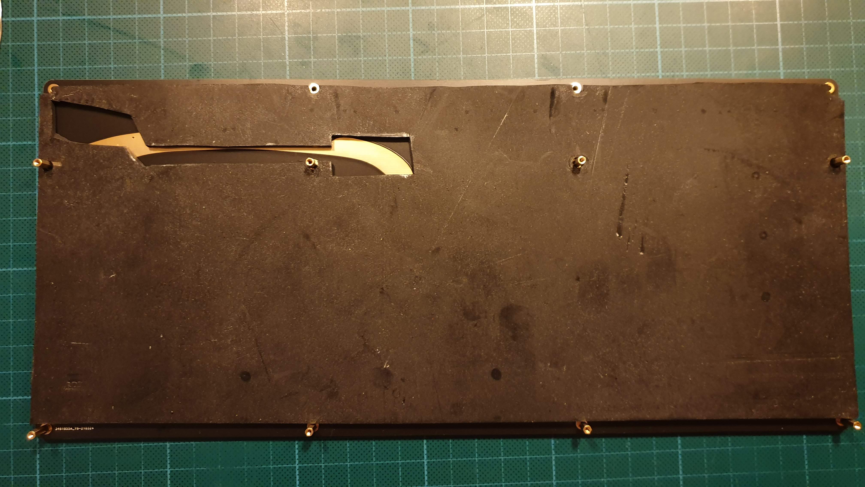
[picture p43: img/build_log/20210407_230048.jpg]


Unfortunately I forgot to take a photo with the actual battery in place as well. I added a small piece of double sided tape on the side of the battery to keep it in place.

# Test again, now with battery, and Bluetooth!
Damn, did it feel good when I paired the keyboard with my desktop and was writing on my own designed wireless keyboard. So cool!

# Assemble complete keyboard
This step is pretty simple, stack all the pieces you have together now and put on the final screws!

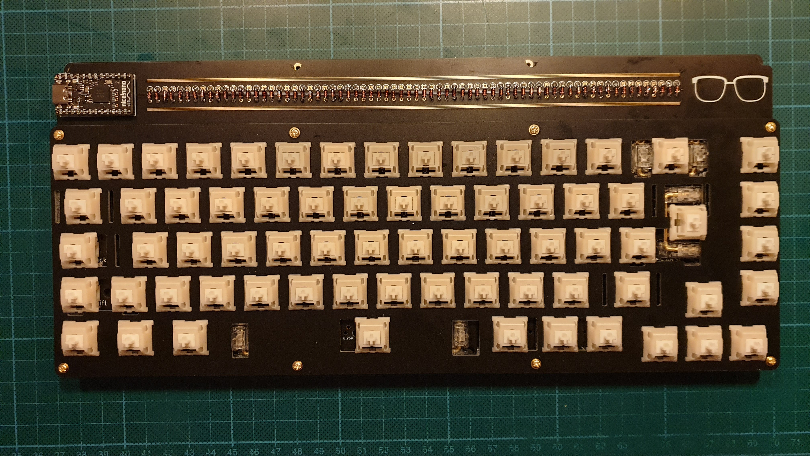
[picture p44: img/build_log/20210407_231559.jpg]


# Put on key caps
So I got an ePBT 9009 kit for this, since my long term goal for this build is to also create a case and the idea is for it to have some 80s-90s computer vibes, like the 9009 color scheme. Also, I got the extra colored Win-key set, really love those and reminds me of using my grandfather's computers (who is also the inspiration for the glass design on the board) and want that aesthetic. Not complicated to put on keycaps, but now it is more easy to see my chosen layout. 

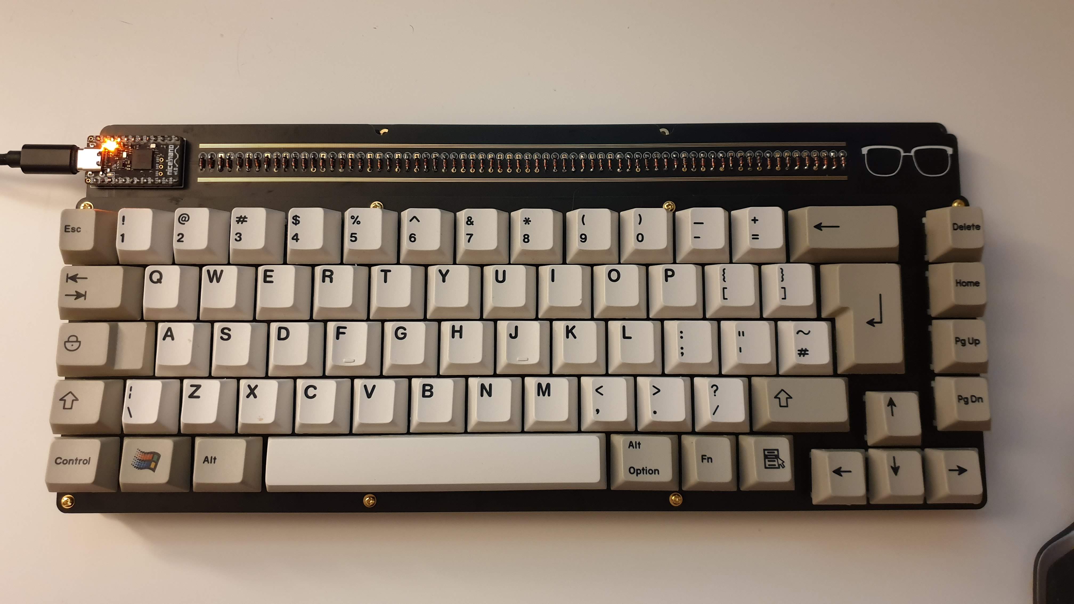
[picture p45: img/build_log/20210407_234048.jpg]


# Final testing
Make sure everything works and feels like you expect it to, which it did! I had a worry that the right arrow key might hit the bottom right case screw when pressed down fully but luckily it just about fits without any modification, win! And now you can just enjoy your keyboard!

Oh, wait...

# Design and order an acrylic window for the top
I wasn't sure how if I should use an acrylic window covering all eight screws on top or if the overlap would look weird so I created two versions. One covering all eight screws on the top part, and one version that only uses the four screw holes on the top of the bottom, which is a bit weaker structurally. I ordered both versions and in both 2 mm and 3 mm clear acrylic to test at home.

Turns out 2 mm acrylic is plenty strong with this amount of screws and without a case the eight screw mount version definitely looks better in my opinion. I do plan on designing a case for it and might use the four screw mount window pieces I now have left over as the window in that case. instead.

And with the acrylic window on, version 1 of the KBIC65, aka Observer65, is finally complete!

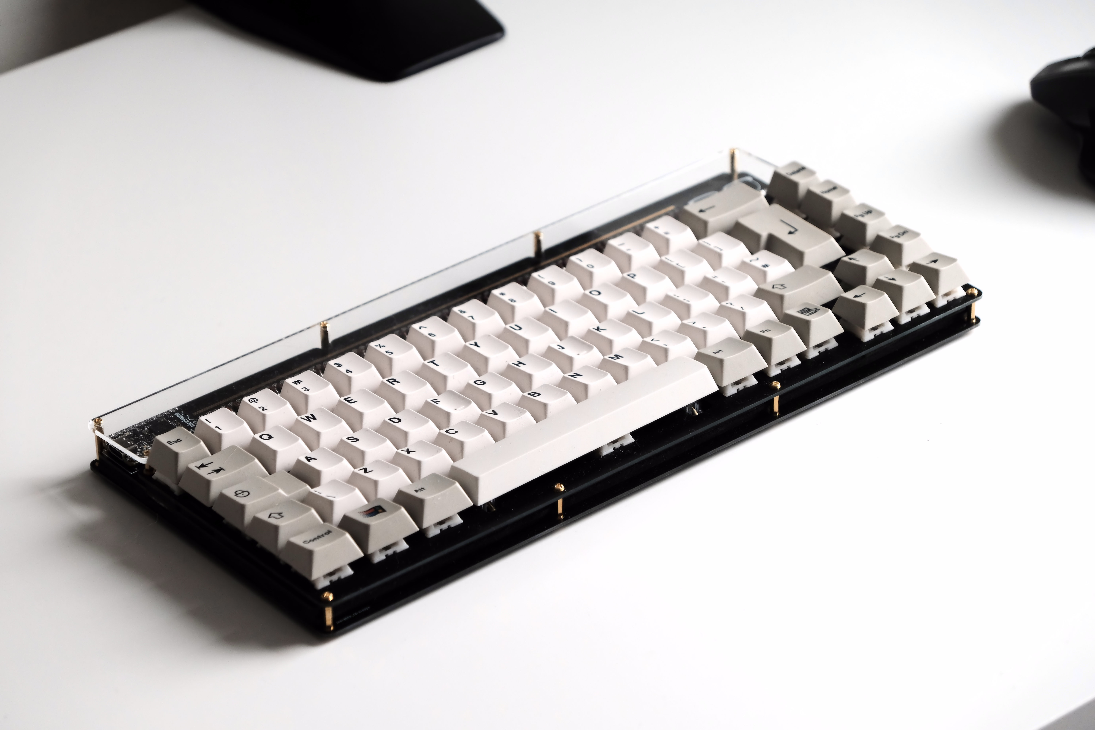
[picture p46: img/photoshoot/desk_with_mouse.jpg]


# Notes if I ever make a V2 or if someone attempts a GB
## PCB front glasses should be in copper
I accidentally forgot to remove a silk screen version of the glasses on the front of the PCB, resulting in what should have been bare gold-ENIG finish copper glasses being white silk screen instead (with a tiny, almost indistinguishable copper margin around them).

## Add holes for soldering on a battery connector
I did not plan enough for attaching the battery and the design would have been neater if there were ports for soldering a battery connector directly.

## Maybe make space bar cutouts in plate and/or PCB to house battery
I originally had a plan to put the battery between the PCB and the plate. Unfortunately the battery I got was too thick (there are thinner ones though) but it could possibly have fit if I had more cutouts around the space bar and put the battery there. The current solutions is not that bad though and will allow me to put in a larger battery as long as it is at most 5 mm thick.

## Move the JLCPCB manufacturing number on the bottom plate
If you choose to have the sun image facing out on the bottom, the production number from JLCPCB will show upward on the edge of the bottom plate, would probably be better to put it on the side or top somewhere instead.

# Update August 2021
I ordered new spacers and found that M2x15mm female-female and M2x3mm+4mm thread male-female spacers are a much better combo for the top window (reduces height different to 0.4mm, which is OK). In addition, Nicell released the [nice!nano v2.0](https://nicekeyboards.com/nice-nano) and [ZMK released a Zephyr update](https://zmk.dev/blog/2021/07/17/zephyr-2-5). Biggest difference is probably the nice!nano v2.0 but the combination has probably pushed my battery life using a 130 mAh LiPo battery to 2 months! Also, having used the keyboard for a while now, I just love the feel. I think the combination Boba U4 switches and the neoprene and foam filled FR4 stack just hits the spot for me.

After a [request on GitHub](https://github.com/b-karl/KBIC65/issues/1) I have also [created a QMK fork for the KBIC65](https://github.com/b-karl/qmk_firmware/tree/add-kbic65-keyboard) that I have confirmed works using an Elite-C rev 4.

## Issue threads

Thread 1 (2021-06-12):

QMK firmware port? and some other questions

sambelgore, 2021-06-12:
Hello! I really liked your work, I'm thinking about building one for myself, but getting nice!nano controller is harder and more expensive in my country, so I'm thinking of using promicro for the build, should it work? (with ZMK and the board itself), I have no programming background so I have no idea on how to look at the firmware, so it would be nice if there is also QMK firmware for this keyboard

and is there anything should I do on JLCPCB besides providing all the gerber zips (plate, bottom plate, and pcb) to order all the necessary plates? (I have never ordered a pcb before)

Thank you!

b-karl, 2021-06-12:
Hi, thanks!

I know, the nice!nano shortage is annoying and it's not the easiest to get a hold of under normal circumstances. I think it should be possible to build ZMK for the ProMicro with minimal changes compared to the nice!nano shield I have in my zmk-config repo, but not 100% sure.

Regarding QMK, I could look at creating a configuration for it. It's a good idea and I know people would appreciate even more if it was available with VIA. I have dabbled with QMK before but only for a KBD75.

On JLCPCB most of the defaults are good, 1.6 mm PCB is important of course to make switches snap in. Then it's up to you to pick the solder mask color and copper finish combo. Mine is black solder mask with ENIG finish, but you can cut cost significantly with a led-free HASL finish but you will get a silver-metal look instead of the gold-brass look of the ENIG finish. Check the upload gerbers in their viewer also to see that it looks OK.

sambelgore, 2021-06-12:
Hello, thank you for the reply!, it is very helpful

I have looked at ZMK documentation and found that it only supports 32-bit and 64-bit controller, so perhaps 8-bit controller like pro micro is not supported(?), though I’m sure that with enough time and help from people who would join my mini local group buy, we would find a way to make the QMK config for it.

I also have another question, is there any newly discovered issue with the current design?

Thank you!

b-karl, 2021-06-29:
Hi,

Sorry for the late reply, I've been very busy.

I think you are correct about ZMK and the ProMicro/8-bit controllers. It's
super cool if you are setting up a local mini group buy, I'd love to create
a QMK config but  don't think I will have time until early August, also, I
don't have a ProMicro at home or any other controller than my (in use)
nice!nano to test it on so it would probably be good if you or someone else
could help me test it.

Two main issues that I think I listed already: (1) unintentional silkscreen
on the front glasses/PCB art, it is supposed to be a pure copper finish and
(2) move the JLCPCB serial number so it doesn't show upwards when the sun
PCB art is facing out/towards the desk.

A couple of other points not documented yet: (1) I ordered new spacers to
try out but haven't tested them yet, main change is to use M2x3mm
male-female spacers instead of my current M2x5mm male-female spacers. (2)
The acrylic window I ended up using (2mm thick) had pretty tight margins on
the screw holes towards the keys and there were slight manufacturing issues
(acrylic was very slightly burnt/warped). I don't really see or think about
it when it's mounted but you can notice it if you inspect it on it's own.
The distance was, however, supposed to be within the tolerances stated by
the laser cutting firm I used (TechStation in Sweden).

On Sat, Jun 12, 2021 at 10:04 PM sambelgore ***@***.***>
wrote:

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

--
Med Vänliga Hälsningar/ Best Regards
Karl Berggren

*Tel:* +4670 44 33 555
*Email:* ***@***.***

b-karl, 2021-06-29:
Another mention, if you are not putting batteries inside the keyboard, you could use 8mm spacers instead of 10 mm to the plate to make it slightly lower profile. Just make sure to match the acrylic window spacers accordingly, 8 mm should go well with 15 mm spacers on the top row and 5 mm male-female spacers on the middle row (or 13 mm female-female + 3 mm male-female).

b-karl, 2021-08-19:
Hi, I finally got some time to work on this.

I started a [QMK fork here](https://github.com/b-karl/qmk_firmware/tree/add-kbic65-keyboard/keyboards/karlb/kbic65) and I have gotten to that point that it compiles without issues but I have not yet tested it on a controller. Got an Elite-C I'm hoping to try it on some day. If you want you can pick that fork and test it yourself also (or I can send you the hexfile). The only thing you might have to change might be the [bootloader](https://beta.docs.qmk.fm/using-qmk/guides/driver_installation_zadig#list-of-known-bootloaders) depending on what controller you use, but think ProMicro and Elite-C use the same. When I see the list it looks like it should be caterina.

b-karl, 2021-08-22:
Update: I changed the bootloader to the default and have tested it now using an Elite-C rev 4, works great You can [pull my branch](https://github.com/b-karl/qmk_firmware/tree/add-kbic65-keyboard/keyboards/karlb/kbic65) to get the code. Did not spend a ton of time on the keymap so make sure you create your own with your preferred layout and mappings :)

Will close the issue now, my first issue ever as an open-source maintainer :D Thanks for submitting the request and questions, feel free to get back to me if you need any more help.

Closed 2021-08-22.

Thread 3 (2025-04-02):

Credit

Chaplood13, 2025-04-02:
I'm an industrial design engineering student

I quite like the aesthetics and mentality of the kb so I ment ahead and designed a case for it I thought you might want to take a look. I credited the keyboard with it's name

[https://www.linkedin.com/posts/
omeranilbolumkan_im-delighted-to-share-this-kbic65-exterior-activity-7312603866343116801-hGOz?
utm_source=share&utm_medium=member_ios&rc
m=ACoAADYpVcoBWJiVdTBUx9G24okVdAXxiDr7
GM8]()

I'd be happy to include you as a collaborator in the project if you'd like me to.
I also would like to use the case as a material to use the project in design awards after finalizing.
I thought I should ask you first though.

You can contact me on reddit
u/Chaplood
or via mail
o.bolumkan@icloud.com

b-karl, 2025-04-04:
Hi! Thanks for reaching out, that's an awesome case, love the combination of wood and metal! You are free to remix and build upon the keyboard, that was my hope with open sourcing it. I know it can be hard to give credit when working with hardware projects but when appropriate please add an acknowledgement that is was based on the KBIC65.

I have a half-baked case project that has been on hold for a couple of years now but I would be happy to discuss ideas or give feedback if you want but you are free to go ahead and do your own thing of course :)

Do you mind if I share your post in the readme?

Chaplood13, 2025-04-06:
I’d be delighted to discuss this further. Of course, you can share it with me. I have midterms this week, but I’ll compose and render a proper animation with a more streamlined design once I’m done. I’m eager to hear any new ideas you may have!

Closed 2025-04-24.

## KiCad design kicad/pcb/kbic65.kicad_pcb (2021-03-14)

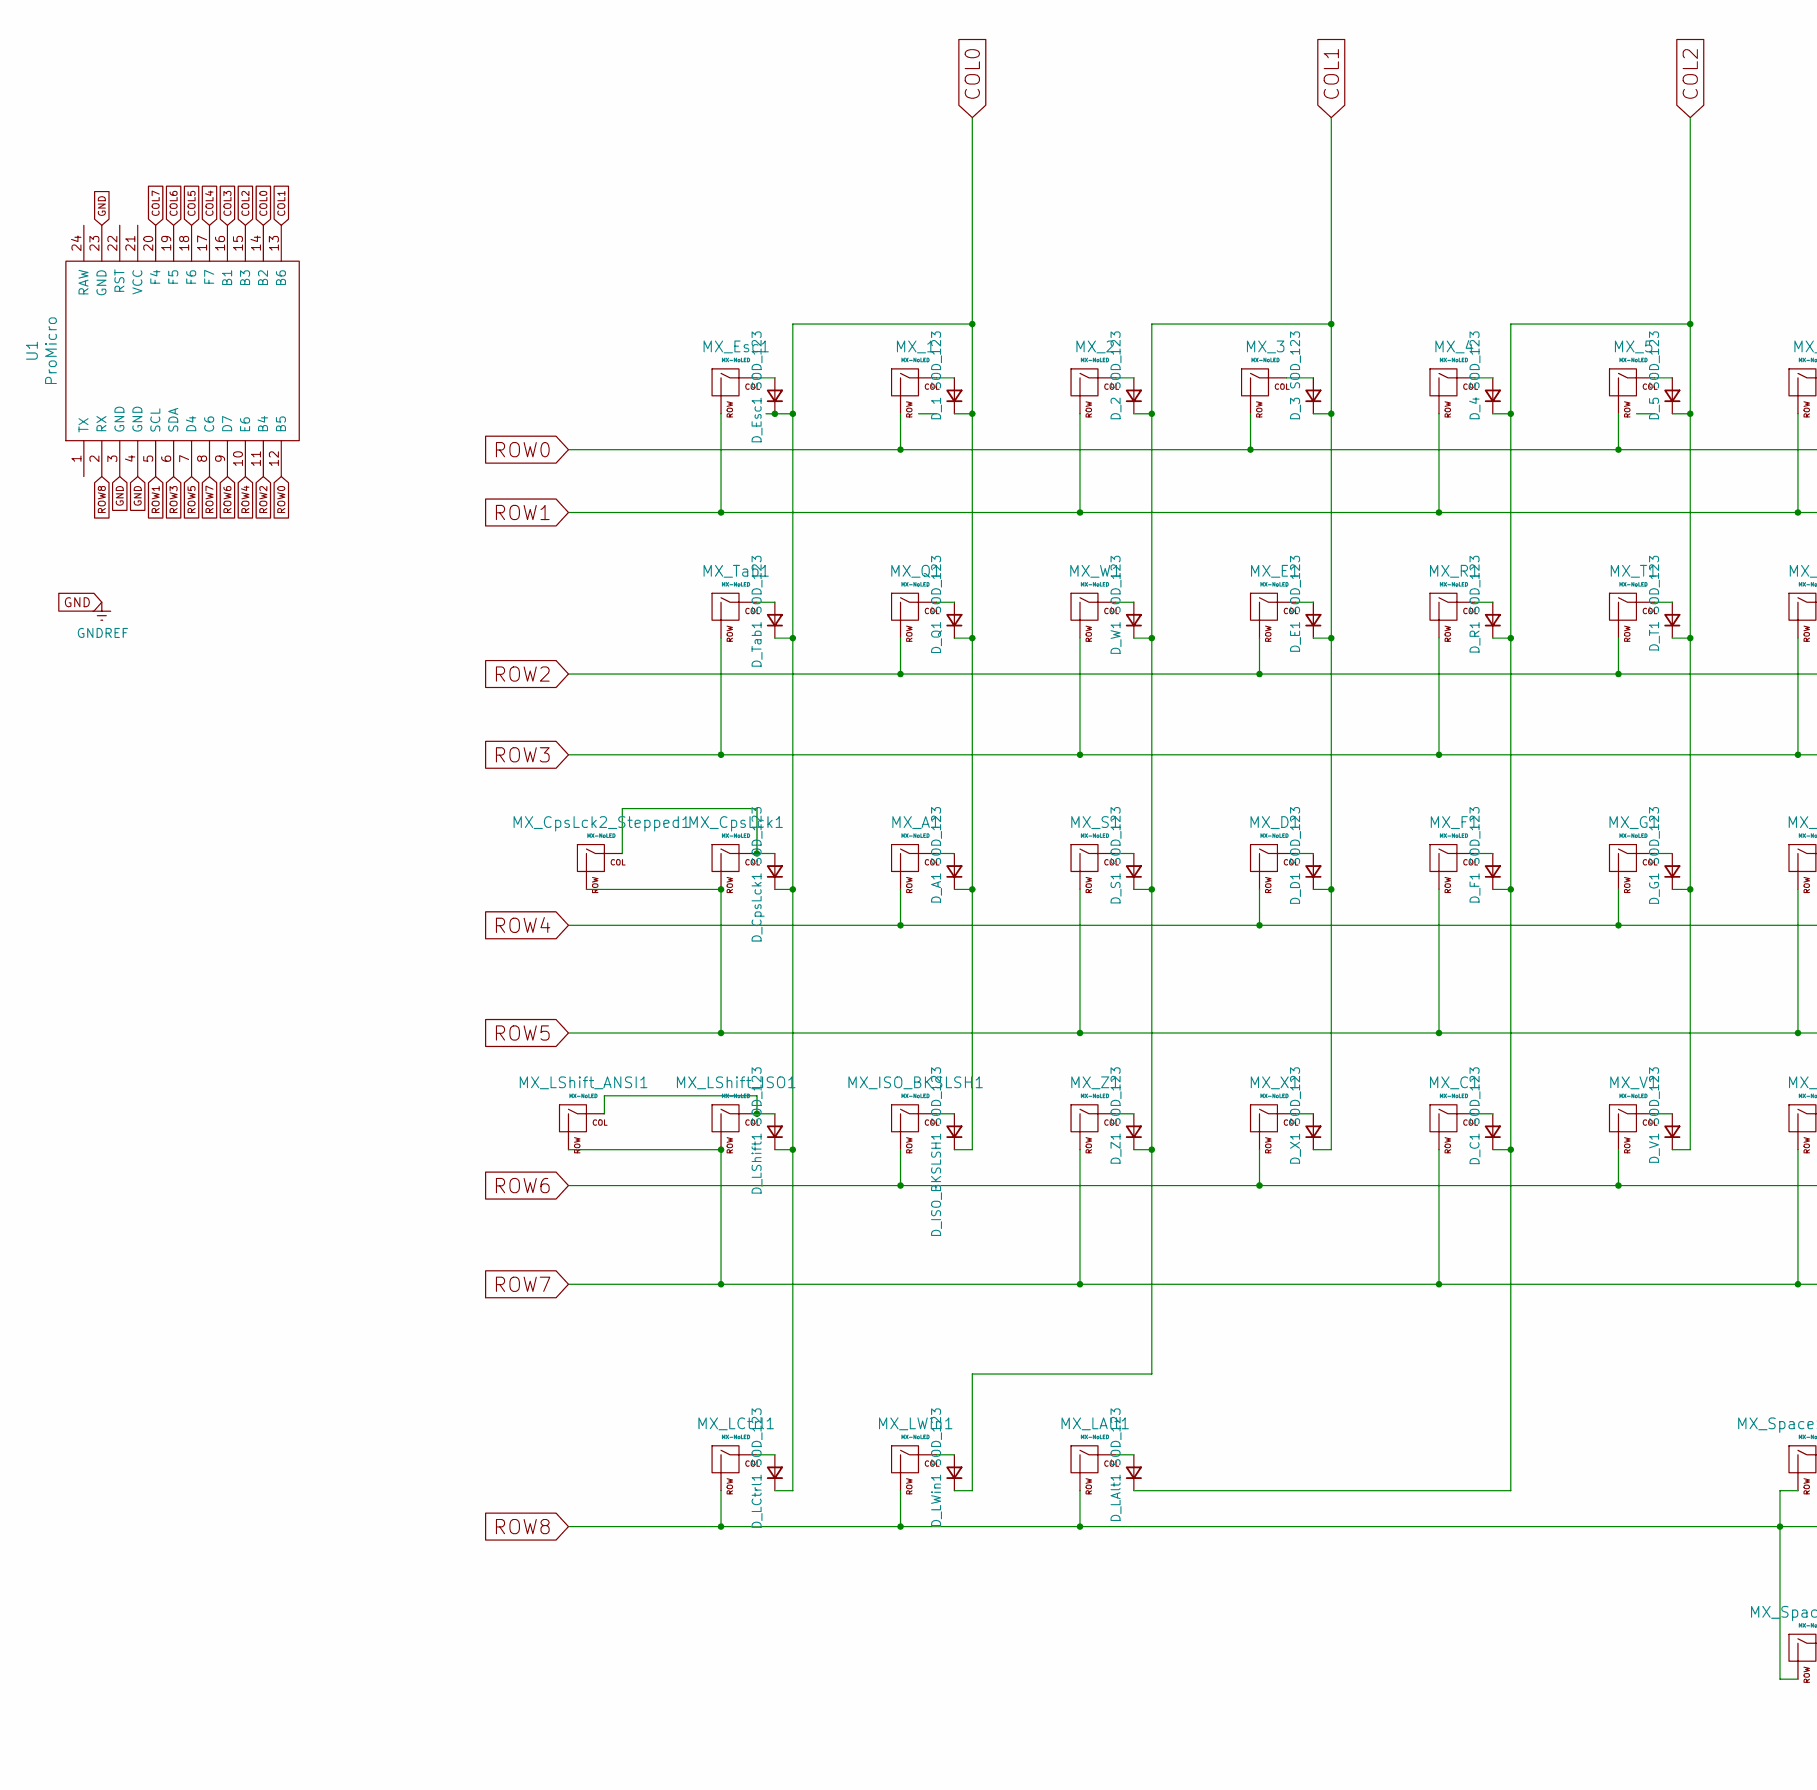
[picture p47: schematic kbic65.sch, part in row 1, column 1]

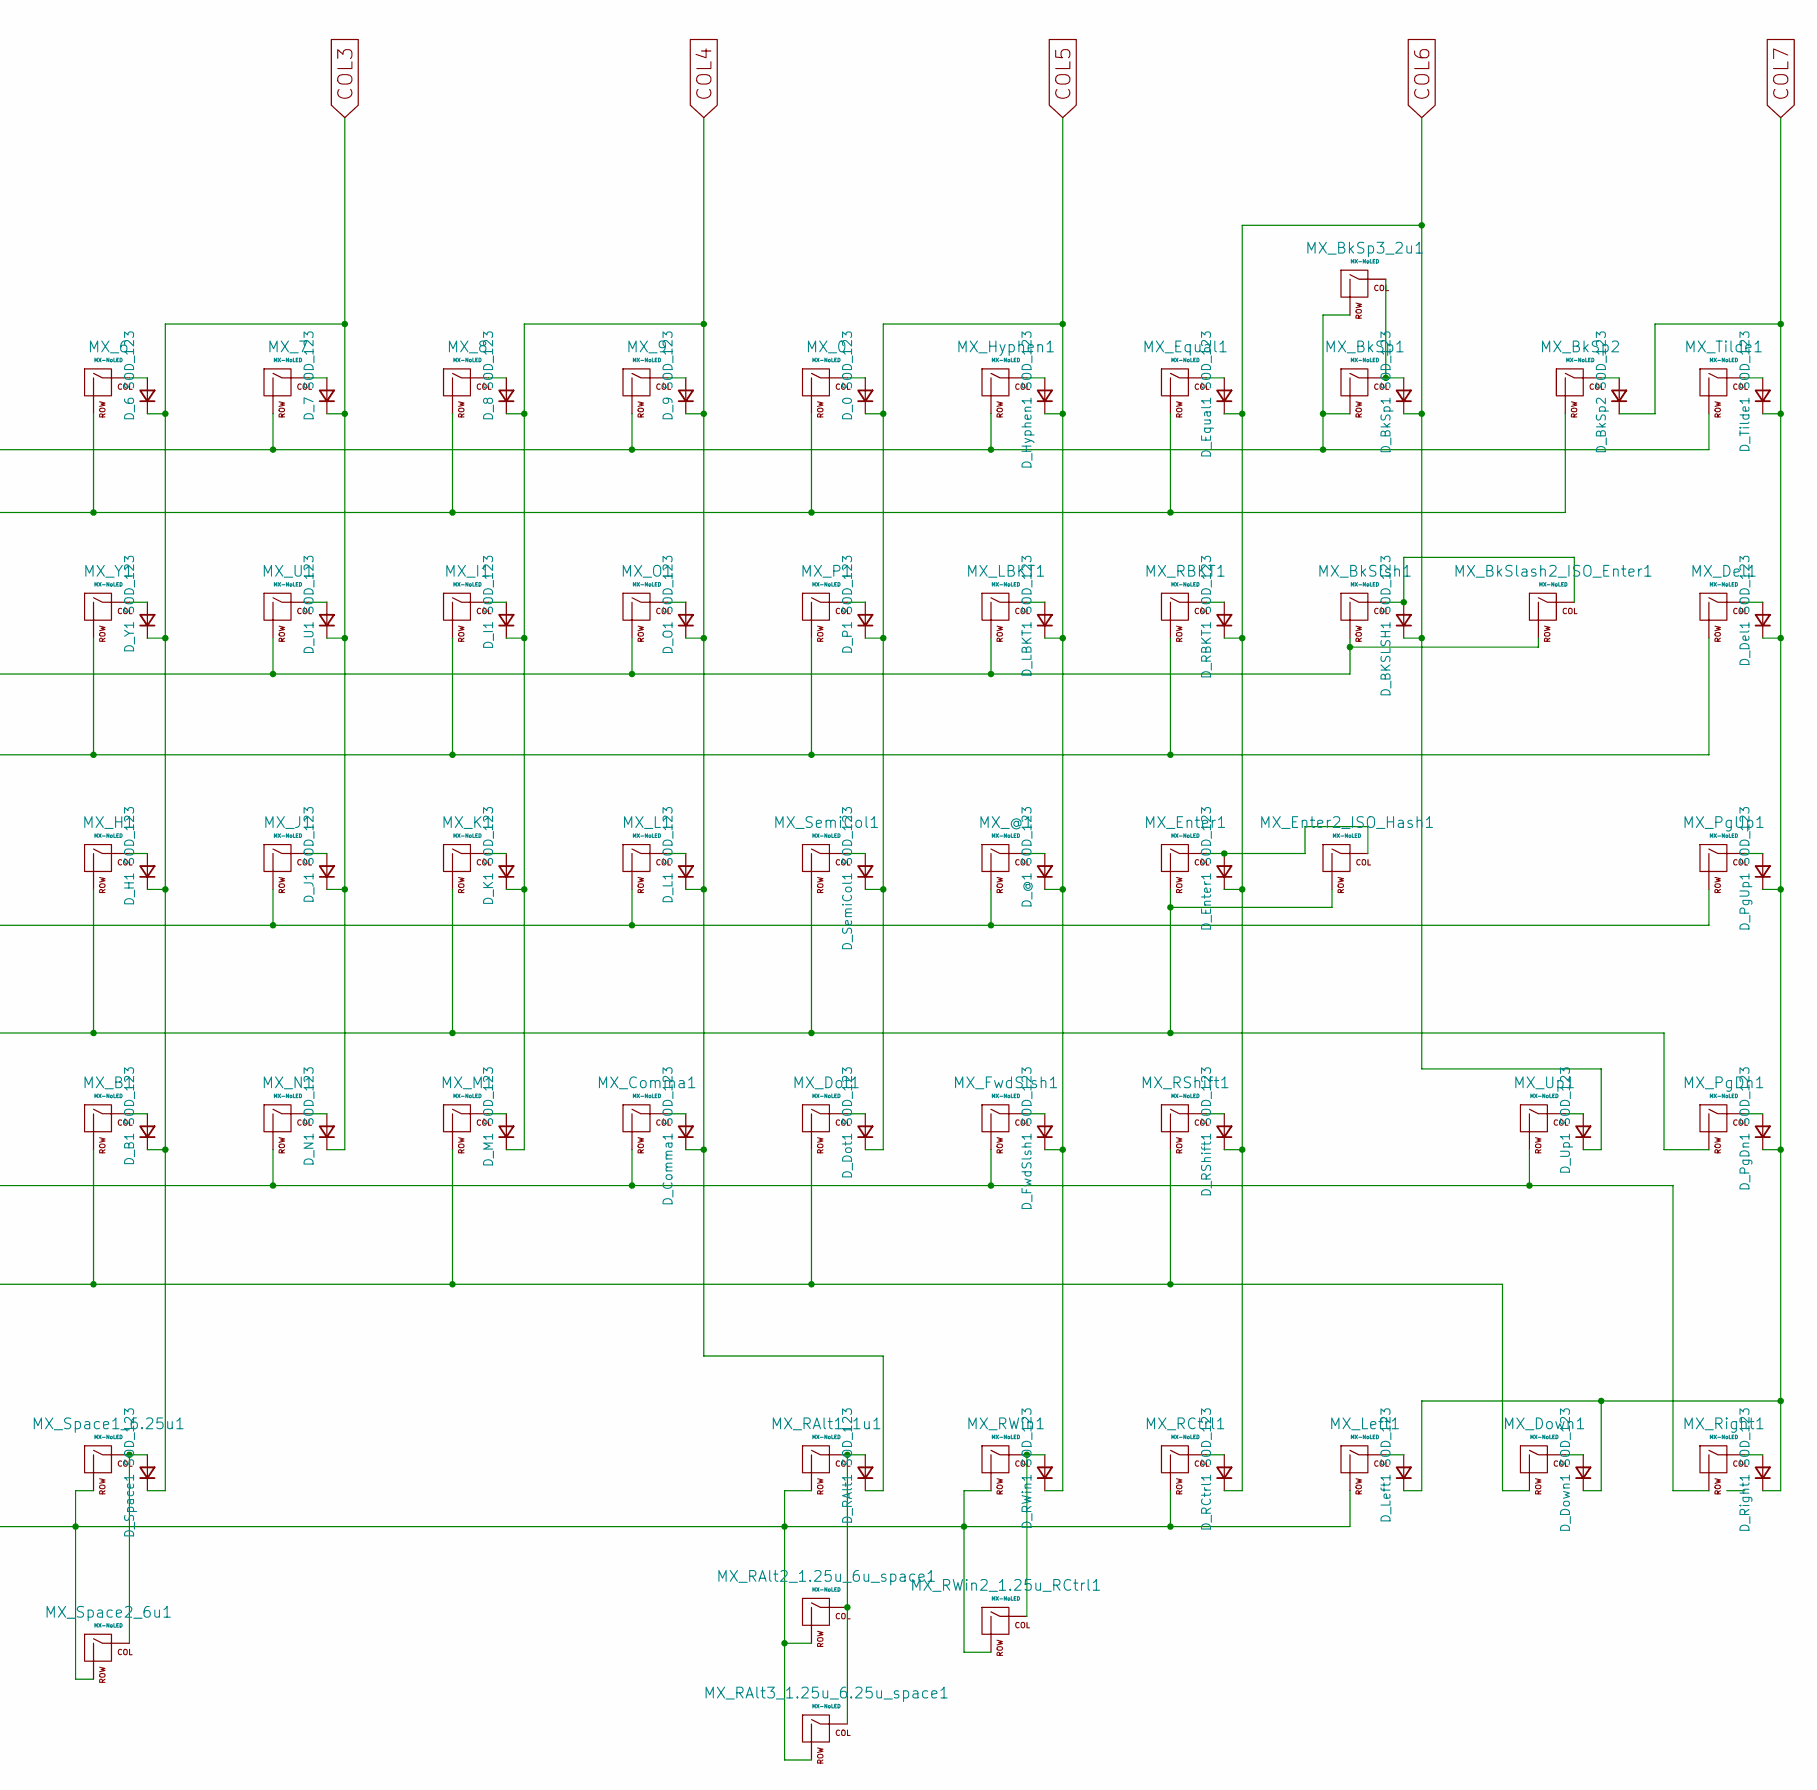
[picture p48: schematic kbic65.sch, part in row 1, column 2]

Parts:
D_0, D_1, D_2, D_3, D_4, D_5, D_6, D_7, D_8, D_9: SOD_123; D_DO-35_SOD27_P5.08mm_Vertical_AnodeUp
D_@1: SOD_123; D_DO-35_SOD27_P5.08mm_Vertical_AnodeUp
D_A1: SOD_123; D_DO-35_SOD27_P5.08mm_Vertical_AnodeUp
D_B1: SOD_123; D_DO-35_SOD27_P5.08mm_Vertical_AnodeUp
D_BKSLSH1: SOD_123; D_DO-35_SOD27_P5.08mm_Vertical_AnodeUp
D_BkSp1, D_BkSp2: SOD_123; D_DO-35_SOD27_P5.08mm_Vertical_AnodeUp
D_C1: SOD_123; D_DO-35_SOD27_P5.08mm_Vertical_AnodeUp
D_Comma1: SOD_123; D_DO-35_SOD27_P5.08mm_Vertical_AnodeUp
D_CpsLck1: SOD_123; D_DO-35_SOD27_P5.08mm_Vertical_AnodeUp
D_D1: SOD_123; D_DO-35_SOD27_P5.08mm_Vertical_AnodeUp
D_Del1: SOD_123; D_DO-35_SOD27_P5.08mm_Vertical_AnodeUp
D_Dot1: SOD_123; D_DO-35_SOD27_P5.08mm_Vertical_AnodeUp
D_Down1: SOD_123; D_DO-35_SOD27_P5.08mm_Vertical_AnodeUp
D_E1: SOD_123; D_DO-35_SOD27_P5.08mm_Vertical_AnodeUp
D_Enter1: SOD_123; D_DO-35_SOD27_P5.08mm_Vertical_AnodeUp
D_Equal1: SOD_123; D_DO-35_SOD27_P5.08mm_Vertical_AnodeUp
D_Esc1: SOD_123; D_DO-35_SOD27_P5.08mm_Vertical_AnodeUp
D_F1: SOD_123; D_DO-35_SOD27_P5.08mm_Vertical_AnodeUp
D_FwdSlsh1: SOD_123; D_DO-35_SOD27_P5.08mm_Vertical_AnodeUp
D_G1: SOD_123; D_DO-35_SOD27_P5.08mm_Vertical_AnodeUp
D_H1: SOD_123; D_DO-35_SOD27_P5.08mm_Vertical_AnodeUp
D_Hyphen1: SOD_123; D_DO-35_SOD27_P5.08mm_Vertical_AnodeUp
D_I1: SOD_123; D_DO-35_SOD27_P5.08mm_Vertical_AnodeUp
D_ISO_BKSLSH1: SOD_123; D_DO-35_SOD27_P5.08mm_Vertical_AnodeUp
D_J1: SOD_123; D_DO-35_SOD27_P5.08mm_Vertical_AnodeUp
D_K1: SOD_123; D_DO-35_SOD27_P5.08mm_Vertical_AnodeUp
D_L1: SOD_123; D_DO-35_SOD27_P5.08mm_Vertical_AnodeUp
D_LAlt1: SOD_123; D_DO-35_SOD27_P5.08mm_Vertical_AnodeUp
D_LBKT1: SOD_123; D_DO-35_SOD27_P5.08mm_Vertical_AnodeUp
D_LCtrl1: SOD_123; D_DO-35_SOD27_P5.08mm_Vertical_AnodeUp
D_LShift1: SOD_123; D_DO-35_SOD27_P5.08mm_Vertical_AnodeUp
D_LWin1: SOD_123; D_DO-35_SOD27_P5.08mm_Vertical_AnodeUp
D_Left1: SOD_123; D_DO-35_SOD27_P5.08mm_Vertical_AnodeUp
D_M1: SOD_123; D_DO-35_SOD27_P5.08mm_Vertical_AnodeUp
D_N1: SOD_123; D_DO-35_SOD27_P5.08mm_Vertical_AnodeUp
D_O1: SOD_123; D_DO-35_SOD27_P5.08mm_Vertical_AnodeUp
D_P1: SOD_123; D_DO-35_SOD27_P5.08mm_Vertical_AnodeUp
D_PgDn1: SOD_123; D_DO-35_SOD27_P5.08mm_Vertical_AnodeUp
D_PgUp1: SOD_123; D_DO-35_SOD27_P5.08mm_Vertical_AnodeUp
D_Q1: SOD_123; D_DO-35_SOD27_P5.08mm_Vertical_AnodeUp
D_R1: SOD_123; D_DO-35_SOD27_P5.08mm_Vertical_AnodeUp
D_RAlt1: SOD_123; D_DO-35_SOD27_P5.08mm_Vertical_AnodeUp
D_RBKT1: SOD_123; D_DO-35_SOD27_P5.08mm_Vertical_AnodeUp
D_RCtrl1: SOD_123; D_DO-35_SOD27_P5.08mm_Vertical_AnodeUp
D_RShift1: SOD_123; D_DO-35_SOD27_P5.08mm_Vertical_AnodeUp
D_RWin1: SOD_123; D_DO-35_SOD27_P5.08mm_Vertical_AnodeUp
D_Right1: SOD_123; D_DO-35_SOD27_P5.08mm_Vertical_AnodeUp
D_S1: SOD_123; D_DO-35_SOD27_P5.08mm_Vertical_AnodeUp
D_SemiCol1: SOD_123; D_DO-35_SOD27_P5.08mm_Vertical_AnodeUp
D_Space1: SOD_123; D_DO-35_SOD27_P5.08mm_Vertical_AnodeUp
D_T1: SOD_123; D_DO-35_SOD27_P5.08mm_Vertical_AnodeUp
D_Tab1: SOD_123; D_DO-35_SOD27_P5.08mm_Vertical_AnodeUp
D_Tilde1: SOD_123; D_DO-35_SOD27_P5.08mm_Vertical_AnodeUp
D_U1: SOD_123; D_DO-35_SOD27_P5.08mm_Vertical_AnodeUp
D_Up1: SOD_123; D_DO-35_SOD27_P5.08mm_Vertical_AnodeUp
D_V1: SOD_123; D_DO-35_SOD27_P5.08mm_Vertical_AnodeUp
D_W1: SOD_123; D_DO-35_SOD27_P5.08mm_Vertical_AnodeUp
D_X1: SOD_123; D_DO-35_SOD27_P5.08mm_Vertical_AnodeUp
D_Y1: SOD_123; D_DO-35_SOD27_P5.08mm_Vertical_AnodeUp
D_Z1: SOD_123; D_DO-35_SOD27_P5.08mm_Vertical_AnodeUp
MX_0, MX_1, MX_2, MX_3, MX_4, MX_5, MX_6, MX_7, MX_8, MX_9: MX-NoLED; MXOnly-1U-NoLED
MX_@1: MX-NoLED; MXOnly-1U-NoLED
MX_A1: MX-NoLED; MXOnly-1U-NoLED
MX_B1: MX-NoLED; MXOnly-1U-NoLED
MX_BkSlash2_ISO_Enter1: MX-NoLED; MXOnly-ISO-ROTATED-ReversedStabilizers-NoLED
MX_BkSlsh1: MX-NoLED; MXOnly-1.5U-NoLED
MX_BkSp1, MX_BkSp2: MX-NoLED; MXOnly-1U-NoLED
MX_BkSp3_2u1: MX-NoLED; MXOnly-2U-NoLED
MX_C1: MX-NoLED; MXOnly-1U-NoLED
MX_Comma1: MX-NoLED; MXOnly-1U-NoLED
MX_CpsLck1: MX-NoLED; MXOnly-1.75U-NoLED
MX_CpsLck2_Stepped1: MX-NoLED; MXOnly-1.25U-NoLED
MX_D1: MX-NoLED; MXOnly-1U-NoLED
MX_Del1: MX-NoLED; MXOnly-1U-NoLED
MX_Dot1: MX-NoLED; MXOnly-1U-NoLED
MX_Down1: MX-NoLED; MXOnly-1U-NoLED
MX_E1: MX-NoLED; MXOnly-1U-NoLED
MX_Enter1: MX-NoLED; MXOnly-2.25U-NoLED
MX_Enter2_ISO_Hash1: MX-NoLED; MXOnly-1U-NoLED
MX_Equal1: MX-NoLED; MXOnly-1U-NoLED
MX_Esc1: MX-NoLED; MXOnly-1U-NoLED
MX_F1: MX-NoLED; MXOnly-1U-NoLED
MX_FwdSlsh1: MX-NoLED; MXOnly-1U-NoLED
MX_G1: MX-NoLED; MXOnly-1U-NoLED
MX_H1: MX-NoLED; MXOnly-1U-NoLED
MX_Hyphen1: MX-NoLED; MXOnly-1U-NoLED
MX_I1: MX-NoLED; MXOnly-1U-NoLED
MX_ISO_BKSLSH1: MX-NoLED; MXOnly-1U-NoLED
MX_J1: MX-NoLED; MXOnly-1U-NoLED
MX_K1: MX-NoLED; MXOnly-1U-NoLED
MX_L1: MX-NoLED; MXOnly-1U-NoLED
MX_LAlt1: MX-NoLED; MXOnly-1.25U-NoLED
MX_LBKT1: MX-NoLED; MXOnly-1U-NoLED
MX_LCtrl1: MX-NoLED; MXOnly-1.25U-NoLED
MX_LShift_ANSI1: MX-NoLED; MXOnly-2.25U-NoLED
MX_LShift_ISO1: MX-NoLED; MXOnly-1.25U-NoLED
MX_LWin1: MX-NoLED; MXOnly-1.25U-NoLED
MX_Left1: MX-NoLED; MXOnly-1U-NoLED
MX_M1: MX-NoLED; MXOnly-1U-NoLED
MX_N1: MX-NoLED; MXOnly-1U-NoLED
MX_O1: MX-NoLED; MXOnly-1U-NoLED
MX_P1: MX-NoLED; MXOnly-1U-NoLED
MX_PgDn1: MX-NoLED; MXOnly-1U-NoLED
MX_PgUp1: MX-NoLED; MXOnly-1U-NoLED
MX_Q1: MX-NoLED; MXOnly-1U-NoLED
MX_R1: MX-NoLED; MXOnly-1U-NoLED
MX_RAlt1_1u1: MX-NoLED; MXOnly-1U-NoLED
MX_RAlt2_1.25u_6u_space1, MX_RAlt3_1.25u_6.25u_space1: MX-NoLED; MXOnly-1.25U-NoLED
MX_RBKT1: MX-NoLED; MXOnly-1U-NoLED
MX_RCtrl1: MX-NoLED; MXOnly-1U-NoLED
MX_RShift1: MX-NoLED; MXOnly-1.75U-NoLED
MX_RWin1, MX_RWin2_1.25u_RCtrl1: MX-NoLED; MXOnly-1U-NoLED
MX_Right1: MX-NoLED; MXOnly-1U-NoLED
MX_S1: MX-NoLED; MXOnly-1U-NoLED
MX_SemiCol1: MX-NoLED; MXOnly-1U-NoLED
MX_Space1_6.25u1: MX-NoLED; MXOnly-6.25U-NoLED
MX_Space2_6u1: MX-NoLED; MXOnly-6U-NoLED
MX_T1: MX-NoLED; MXOnly-1U-NoLED
MX_Tab1: MX-NoLED; MXOnly-1.5U-NoLED
MX_Tilde1: MX-NoLED; MXOnly-1U-NoLED
MX_U1: MX-NoLED; MXOnly-1U-NoLED
MX_Up1: MX-NoLED; MXOnly-1U-NoLED
MX_V1: MX-NoLED; MXOnly-1U-NoLED
MX_W1: MX-NoLED; MXOnly-1U-NoLED
MX_X1: MX-NoLED; MXOnly-1U-NoLED
MX_Y1: MX-NoLED; MXOnly-1U-NoLED
MX_Z1: MX-NoLED; MXOnly-1U-NoLED
U1: ProMicro; ArduinoProMicro-ZigZag

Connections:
COL0: D_1.1 (K), D_A1.1 (K), D_CpsLck1.1 (K), D_Esc1.1 (K), D_ISO_BKSLSH1.1 (K), D_LCtrl1.1 (K), D_LShift1.1 (K), D_Q1.1 (K), D_Tab1.1 (K), U1.14 (B2)
COL1: D_2.1 (K), D_3.1 (K), D_D1.1 (K), D_E1.1 (K), D_LWin1.1 (K), D_S1.1 (K), D_W1.1 (K), D_X1.1 (K), D_Z1.1 (K), U1.13 (B6)
COL2: D_4.1 (K), D_5.1 (K), D_C1.1 (K), D_F1.1 (K), D_G1.1 (K), D_LAlt1.1 (K), D_R1.1 (K), D_T1.1 (K), D_V1.1 (K), U1.15 (B3)
COL3: D_6.1 (K), D_7.1 (K), D_B1.1 (K), D_H1.1 (K), D_J1.1 (K), D_N1.1 (K), D_Space1.1 (K), D_U1.1 (K), D_Y1.1 (K), U1.16 (B1)
COL4: D_8.1 (K), D_9.1 (K), D_Comma1.1 (K), D_I1.1 (K), D_K1.1 (K), D_L1.1 (K), D_M1.1 (K), D_O1.1 (K), D_RAlt1.1 (K), U1.17 (F7)
COL5: D_0.1 (K), D_@1.1 (K), D_Dot1.1 (K), D_FwdSlsh1.1 (K), D_Hyphen1.1 (K), D_LBKT1.1 (K), D_P1.1 (K), D_RWin1.1 (K), D_SemiCol1.1 (K), U1.18 (F6)
COL6: D_BKSLSH1.1 (K), D_BkSp1.1 (K), D_Enter1.1 (K), D_Equal1.1 (K), D_RBKT1.1 (K), D_RCtrl1.1 (K), D_RShift1.1 (K), D_Up1.1 (K), U1.19 (F5)
COL7: D_BkSp2.1 (K), D_Del1.1 (K), D_Down1.1 (K), D_Left1.1 (K), D_PgDn1.1 (K), D_PgUp1.1 (K), D_Right1.1 (K), D_Tilde1.1 (K), U1.20 (F4)
GND: U1.3 (GND), U1.4 (GND), U1.23 (GND)
unnamed: D_0.2 (A), MX_0.1 (COL)
unnamed: D_1.2 (A), MX_1.1 (COL)
unnamed: D_2.2 (A), MX_2.1 (COL)
unnamed: D_3.2 (A), MX_3.1 (COL)
unnamed: D_4.2 (A), MX_4.1 (COL)
unnamed: D_5.2 (A), MX_5.1 (COL)
unnamed: D_6.2 (A), MX_6.1 (COL)
unnamed: D_7.2 (A), MX_7.1 (COL)
unnamed: D_8.2 (A), MX_8.1 (COL)
unnamed: D_9.2 (A), MX_9.1 (COL)
unnamed: D_@1.2 (A), MX_@1.1 (COL)
unnamed: D_A1.2 (A), MX_A1.1 (COL)
unnamed: D_B1.2 (A), MX_B1.1 (COL)
unnamed: D_BKSLSH1.2 (A), MX_BkSlash2_ISO_Enter1.1 (COL), MX_BkSlsh1.1 (COL)
unnamed: D_BkSp1.2 (A), MX_BkSp1.1 (COL), MX_BkSp3_2u1.1 (COL)
unnamed: D_BkSp2.2 (A), MX_BkSp2.1 (COL)
unnamed: D_C1.2 (A), MX_C1.1 (COL)
unnamed: D_Comma1.2 (A), MX_Comma1.1 (COL)
unnamed: D_CpsLck1.2 (A), MX_CpsLck1.1 (COL), MX_CpsLck2_Stepped1.1 (COL)
unnamed: D_D1.2 (A), MX_D1.1 (COL)
unnamed: D_Del1.2 (A), MX_Del1.1 (COL)
unnamed: D_Dot1.2 (A), MX_Dot1.1 (COL)
unnamed: D_Down1.2 (A), MX_Down1.1 (COL)
unnamed: D_E1.2 (A), MX_E1.1 (COL)
unnamed: D_Enter1.2 (A), MX_Enter1.1 (COL), MX_Enter2_ISO_Hash1.1 (COL)
unnamed: D_Equal1.2 (A), MX_Equal1.1 (COL)
unnamed: D_Esc1.2 (A), MX_Esc1.1 (COL)
unnamed: D_F1.2 (A), MX_F1.1 (COL)
unnamed: D_FwdSlsh1.2 (A), MX_FwdSlsh1.1 (COL)
unnamed: D_G1.2 (A), MX_G1.1 (COL)
unnamed: D_H1.2 (A), MX_H1.1 (COL)
unnamed: D_Hyphen1.2 (A), MX_Hyphen1.1 (COL)
unnamed: D_I1.2 (A), MX_I1.1 (COL)
unnamed: D_ISO_BKSLSH1.2 (A), MX_ISO_BKSLSH1.1 (COL)
unnamed: D_J1.2 (A), MX_J1.1 (COL)
unnamed: D_K1.2 (A), MX_K1.1 (COL)
unnamed: D_L1.2 (A), MX_L1.1 (COL)
unnamed: D_LAlt1.2 (A), MX_LAlt1.1 (COL)
unnamed: D_LBKT1.2 (A), MX_LBKT1.1 (COL)
unnamed: D_LCtrl1.2 (A), MX_LCtrl1.1 (COL)
unnamed: D_LShift1.2 (A), MX_LShift_ANSI1.1 (COL), MX_LShift_ISO1.1 (COL)
unnamed: D_LWin1.2 (A), MX_LWin1.1 (COL)
unnamed: D_Left1.2 (A), MX_Left1.1 (COL)
unnamed: D_M1.2 (A), MX_M1.1 (COL)
unnamed: D_N1.2 (A), MX_N1.1 (COL)
unnamed: D_O1.2 (A), MX_O1.1 (COL)
unnamed: D_P1.2 (A), MX_P1.1 (COL)
unnamed: D_PgDn1.2 (A), MX_PgDn1.1 (COL)
unnamed: D_PgUp1.2 (A), MX_PgUp1.1 (COL)
unnamed: D_Q1.2 (A), MX_Q1.1 (COL)
unnamed: D_R1.2 (A), MX_R1.1 (COL)
unnamed: D_RAlt1.2 (A), MX_RAlt1_1u1.1 (COL), MX_RAlt2_1.25u_6u_space1.1 (COL), MX_RAlt3_1.25u_6.25u_space1.1 (COL)
unnamed: D_RBKT1.2 (A), MX_RBKT1.1 (COL)
unnamed: D_RCtrl1.2 (A), MX_RCtrl1.1 (COL)
unnamed: D_RShift1.2 (A), MX_RShift1.1 (COL)
unnamed: D_RWin1.2 (A), MX_RWin1.1 (COL), MX_RWin2_1.25u_RCtrl1.1 (COL)
unnamed: D_Right1.2 (A), MX_Right1.1 (COL)
unnamed: D_S1.2 (A), MX_S1.1 (COL)
unnamed: D_SemiCol1.2 (A), MX_SemiCol1.1 (COL)
unnamed: D_Space1.2 (A), MX_Space1_6.25u1.1 (COL), MX_Space2_6u1.1 (COL)
unnamed: D_T1.2 (A), MX_T1.1 (COL)
unnamed: D_Tab1.2 (A), MX_Tab1.1 (COL)
unnamed: D_Tilde1.2 (A), MX_Tilde1.1 (COL)
unnamed: D_U1.2 (A), MX_U1.1 (COL)
unnamed: D_Up1.2 (A), MX_Up1.1 (COL)
unnamed: D_V1.2 (A), MX_V1.1 (COL)
unnamed: D_W1.2 (A), MX_W1.1 (COL)
unnamed: D_X1.2 (A), MX_X1.1 (COL)
unnamed: D_Y1.2 (A), MX_Y1.1 (COL)
unnamed: D_Z1.2 (A), MX_Z1.1 (COL)
ROW0: MX_1.2 (ROW), MX_3.2 (ROW), MX_5.2 (ROW), MX_7.2 (ROW), MX_9.2 (ROW), MX_BkSp1.2 (ROW), MX_BkSp3_2u1.2 (ROW), MX_Hyphen1.2 (ROW), MX_Tilde1.2 (ROW), U1.12 (B5)
ROW1: MX_0.2 (ROW), MX_2.2 (ROW), MX_4.2 (ROW), MX_6.2 (ROW), MX_8.2 (ROW), MX_BkSp2.2 (ROW), MX_Equal1.2 (ROW), MX_Esc1.2 (ROW), U1.5 (SCL)
ROW2: MX_BkSlash2_ISO_Enter1.2 (ROW), MX_BkSlsh1.2 (ROW), MX_E1.2 (ROW), MX_LBKT1.2 (ROW), MX_O1.2 (ROW), MX_Q1.2 (ROW), MX_T1.2 (ROW), MX_U1.2 (ROW), U1.11 (B4)
ROW3: MX_Del1.2 (ROW), MX_I1.2 (ROW), MX_P1.2 (ROW), MX_R1.2 (ROW), MX_RBKT1.2 (ROW), MX_Tab1.2 (ROW), MX_W1.2 (ROW), MX_Y1.2 (ROW), U1.6 (SDA)
ROW4: MX_@1.2 (ROW), MX_A1.2 (ROW), MX_D1.2 (ROW), MX_G1.2 (ROW), MX_J1.2 (ROW), MX_L1.2 (ROW), MX_PgUp1.2 (ROW), U1.10 (E6)
ROW5: MX_CpsLck1.2 (ROW), MX_CpsLck2_Stepped1.2 (ROW), MX_Enter1.2 (ROW), MX_Enter2_ISO_Hash1.2 (ROW), MX_F1.2 (ROW), MX_H1.2 (ROW), MX_K1.2 (ROW), MX_PgDn1.2 (ROW), MX_S1.2 (ROW), MX_SemiCol1.2 (ROW), U1.7 (D4)
ROW6: MX_Comma1.2 (ROW), MX_FwdSlsh1.2 (ROW), MX_ISO_BKSLSH1.2 (ROW), MX_N1.2 (ROW), MX_Right1.2 (ROW), MX_Up1.2 (ROW), MX_V1.2 (ROW), MX_X1.2 (ROW), U1.9 (D7)
ROW7: MX_B1.2 (ROW), MX_C1.2 (ROW), MX_Dot1.2 (ROW), MX_Down1.2 (ROW), MX_LShift_ANSI1.2 (ROW), MX_LShift_ISO1.2 (ROW), MX_M1.2 (ROW), MX_RShift1.2 (ROW), MX_Z1.2 (ROW), U1.8 (C6)
ROW8: MX_LAlt1.2 (ROW), MX_LCtrl1.2 (ROW), MX_LWin1.2 (ROW), MX_Left1.2 (ROW), MX_RAlt1_1u1.2 (ROW), MX_RAlt2_1.25u_6u_space1.2 (ROW), MX_RAlt3_1.25u_6.25u_space1.2 (ROW), MX_RCtrl1.2 (ROW), MX_RWin1.2 (ROW), MX_RWin2_1.25u_RCtrl1.2 (ROW), MX_Space1_6.25u1.2 (ROW), MX_Space2_6u1.2 (ROW), U1.2 (RX)

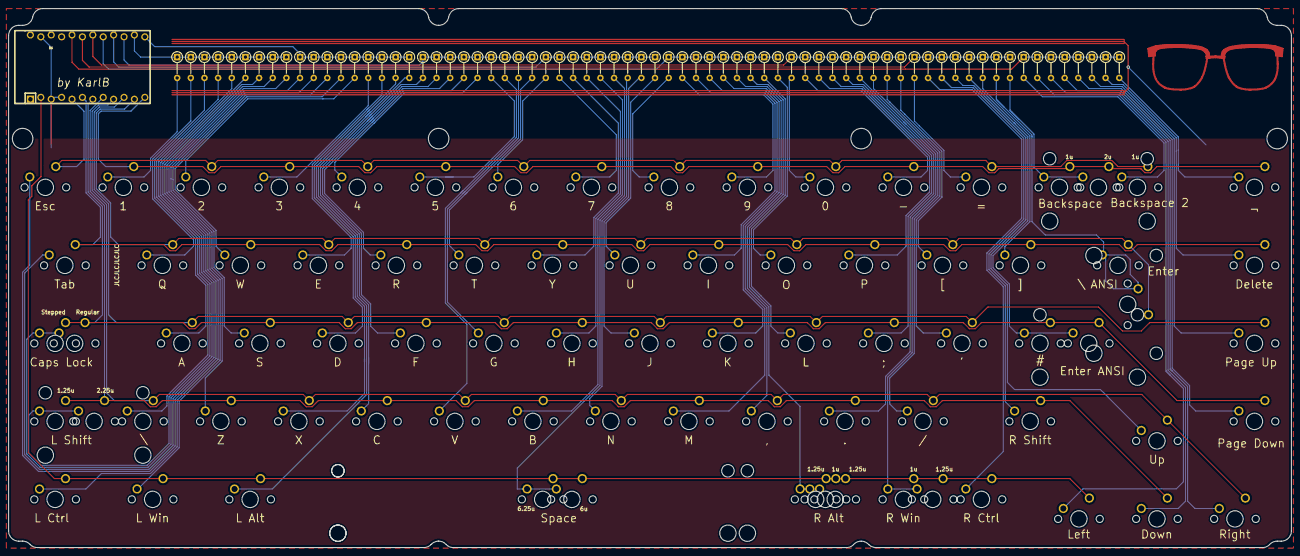
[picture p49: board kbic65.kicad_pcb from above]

Board: 2 copper layers, 313.3 x 131.6 mm, 150 parts (0 on the bottom side), 88 nets.

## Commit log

2020-11-08 Created project
    [kbic65.kicad_pcb, kbic65.sch]
2020-11-08 Added kebbio footprints
2020-11-08 added libraries to kicad
2020-11-08 added pro micro to kicad
2020-11-09 saved work in kicad
    [kbic65.sch]
2020-12-07 Added key matrix
    [kbic65.sch]
2020-12-12 Created new matrix and labeled ProMicro footprint
    [kbic65.sch]
2020-12-12 Naming matrix components
    [kbic65.sch]
2020-12-13 Added footprints
    [kbic65.sch]
2020-12-14 Placed components on PCB and imported dxf
    [kbic65.sch]
2020-12-14 Added and updated footprints
    [kbic65.kicad_pcb]
2020-12-16 Redrew schematic with all extra footprints
    [kbic65.kicad_pcb, kbic65.sch]
2020-12-16 Changed layout to top windows and rearranging diodes
    [kbic65.kicad_pcb, kbic65.sch]
2020-12-17 Changed diode to row2col instead to make better wiring, rearranging diode footprints
    [kbic65.kicad_pcb, kbic65.sch]
2020-12-19 Rearranged diodes for wiring
    [kbic65.kicad_pcb]
2020-12-19 Rearranged rows on promicro footprint
    [kbic65.kicad_pcb, kbic65.sch]
2020-12-19 Simple arrangement of diodes
    [kbic65.kicad_pcb]
2020-12-22 Reverted back to single line of diodes
    [kbic65.kicad_pcb]
2021-01-13 Changed outline to inkscape generated and aligned it
    [kbic65.kicad_pcb]
2021-01-13 Finally started wiring
    [kbic65.kicad_pcb]
2021-01-20 Changed structure of repo
    [kbic65.kicad_pcb, kbic65.sch]
2021-01-20 More wiring
    [kbic65.kicad_pcb]
2021-01-21 Sooo much wiring
    [kbic65.kicad_pcb]
2021-01-22 Wiring 4 life
    [kbic65.kicad_pcb, kbic65.sch]
2021-01-23 Completed first version of full wiring
    [kbic65.kicad_pcb, kbic65.sch]
2021-01-24 Cleared wiring, starting over with default tracks
    [kbic65.kicad_pcb]
2021-01-24 Starting new wiring
    [kbic65.kicad_pcb, kbic65.sch]
2021-01-26 Updated wiring, added drill holes and cut outline
    [kbic65.kicad_pcb]
2021-01-27 Fixed 6u spacebar
    [kbic65.kicad_pcb, kbic65.sch]
2021-01-27 Merged all cutouts and added fillets in plate
2021-01-27 Thinking about plate size, added current state of pcb
2021-01-28 Drew first version of plate
2021-02-01 Fixed with bottom plate
2021-02-15 Updated board design and rewired, starting silkscreens
    [PCB_Holes.dxf, PCB_Outline.dxf, PCB_Silkscreen.dxf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]
2021-02-15 moved some references
    [kbic65.kicad_pcb]
2021-02-15 fixed gaps in pcb outline
    [PCB_Outline.dxf, kbic65.kicad_pcb]
2021-02-15 looking at filling
    [kbic65.kicad_pcb]
2021-02-16 pre-updating gnd
    [kbic65.kicad_pcb, kbic65.sch]
2021-02-16 adding copper fill
    [kbic65.kicad_pcb]
2021-02-16 readded missing silkscreen text
    [kbic65.kicad_pcb]
2021-02-16 added signature
    [kbic65.kicad_pcb]
2021-02-17 added styled lines to top
    [kbic65.kicad_pcb, kbic65.sch]
2021-02-17 started with bottom plate
    [Bottom_Holes.dxf, Bottom_Outline.dxf, Bottom_Silkscreen.dxf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]
2021-02-19 finished designing bottom plate
    [Bottom_Holes.dxf, Bottom_Silkscreen.dxf]
2021-02-19 finished mounting plate
    [Plate_Holes.dxf, Plate_Outline.dxf, kbic65-plate.kicad_pcb]
2021-02-19 fixed silkscreen on bottom plate
    [kbic65-bottom.kicad_pcb]
2021-02-21 added ref placeholders and created gerbers
    [kbic65-B_Cu.gbr, kbic65-B_Mask.gbr, kbic65-B_SilkS.gbr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]
2021-03-14 changed bottom glasses to cu
    [kbic65-bottom.kicad_pcb, kbic65.kicad_pcb]
2021-03-17 added sun footprint
2021-03-23 added swanky sun (imho)
    [kbic65-bottom.kicad_pcb]
2021-03-23 created new gerbers for bototm
    [kbic65-bottom-B_Cu.gbr, kbic65-bottom-B_Mask.gbr, kbic65-bottom-B_SilkS.gbr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]
2021-04-15 created drawings for top window
    [Window_Large.dxf, Window_Small.dxf, kbic65.sch]
2021-04-15 combined window drawings
    [Window_Combined.dxf]
2021-08-24 removed gerbers
    [kbic65-B_Cu.gbr, kbic65-B_Mask.gbr, kbic65-B_SilkS.gbr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]
2021-08-24 rearranged kicad folder
    [kbic65.kicad_pcb, kbic65.sch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]
2021-08-26 added empty schematics files for bottom and top plate
    [kbic65-bottom.sch, kbic65-plate.sch]
